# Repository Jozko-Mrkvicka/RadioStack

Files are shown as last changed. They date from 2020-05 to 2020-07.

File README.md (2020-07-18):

TODO
====
- Software AVR:
	- Change folder structure in some more sensible way.
	- Polish header files + including.
	- I can`t include delay.h to other files than main one. Find out why and replace all workarounds.
	- Add keyword const to all function declarations where possible.
	- Add description to all functions and describe all input and output parameters.
	- Add description to all modules.
	- There is potential problem with settings of bits in registers to zero. I do it incorrectly. Fix it!!

- Eagle:
	- ADF:
		- Change ELMA encoder to "normal" (single) one.
		- Display will be selected with push button on encoder.
		- Decimal point will define which display is currently selected.
		- Adjust DWG accordingly
		- Draw first board.
		- Think about second board (find out how many more IO modules can be added to the address space).

- Buy:
	- Jumpers.
	- Female pin headers with long pins.

- Other ideas:
	- ELMA encoders not fully working in one NavComm module. Probably mechanically damaged. Fix it or resolder.
	- Holes for buttons and knobs on NavComm module are too small. This problem should be already fixed in Eagle/AutoCAD drawings but check it once again.
	- Change front panel to plastic one:
		- It will be thicker. 
		- Add couple of bolts + nuts to attach it firmly to the rest of a module. 
		- It will have also bevelled edges. 
	- Encoder push buttons in NavComm modules not enabled yet. Add them.
	- Change pin headers to another ones with longer pins to create more space between PCB boards. The reason is to create more space for bolts/nuts to attach the device to a box/cover.

- Unsorted legacy mess:
	SVN
	===
	- nahrat vsetky dokumenty z mejlov (a mozno aj mejly samotne) do zlozky Admin
	- pridat vsetky subory eagle.epf na ignor list

	AutoCAD
	=======
	- zistit preco je XPDR tmavsi ako ostatne casti
	- vypatrat ci existuje nieco ako globalne konstanty/parametre, aby som mohol pouzivat rovnaky rozmer vo viacerych vykresoch
	- (XPDR) pridat objekt "obycajny" prepinac (ako bol na starom transponderu)

	Eagle
	=====
	- (niektore) Konektory na doske NavCom_Board_1 a NavCom_Board_2 su vlozene do vrstvy TOP, ale v skutocnosti sa nachadzaju vzadu (BOTTOM). To sposobi ze pri vyrobe sa ich obrysy vytlacia na opacnej strane dosky (tPlaces vs. bPlaces). Preto je treba tieto suciastky prehodit (Mirror) do spravnej vrstvy. 
	- NavComm 2.1/Board 2 - tlacitka T1 az T4 - trojice dierok pre piny su velmi blizko pri sebe, tlacitko nechce zaliezt do dierok (opravit aj v AutoCADe)
	- (nav/comm) mozno by bolo dobre odstranit vyvody na tlacitko "S" z enkoderov ELMA
	- ku kazdemu enkoderu pridat 2 kondenzatory
	- prepisat popisky tlacitiek T1 az T4 na BTN1 az BTN4

	Programovanie
	=============
	- vysvetlit naco sluzi signal Latch Reset
	- presunut radiostack.h zo zlozky modules/include do common/includes, alebo daco podobne

	Kupit
	=====
	- Dutinková lišta BL810GD
	- este jednu Elmu + hmatniky
	- jumpery
	- MCP23016 (2x)
	- 279-RGP0207CHJ470M (16x odpor z Mouseru)
	- dual shaft/dual concentric enkoder (2 channels) - Mouser
	- doniest z domu ockovy kluc kvoli hmatniku na Elmu
	- 2x Avago HDSP-711E

	======================================================================
	// -c		 skompiluje zdrojak ".c" do objektoveho kodu ".o"
	// -Wall	 warning all
	// -pedantic
	// -o 		 pomenuje vystupny subor
	avr-gcc -c pokus.c -Wall -pedantic -o vystup.o

	// zkompiluje a zlinkuje do ".exe"
	avr-gcc pokus.c libkniznica.a

	// -q	quick append - zalozi archiv / prida ".o" subor do archivu
	avr-ar -q libfnc.a fnc3.o

	// -t	zobrazi vsetky ".o" subory v archive
	avr-ar -t libfnc.a

	// -d	delete - vymaze ".o" subor z archivu
	avr-ar -d libfnc.a fnc3.o

	// -p 	typ procesoru (m8, t13, t2313, ...)
	// -c 	typ programatoru (AVRispmkII)
	// -P 	port ku ktoremu je programator pripojeny (usb)
	// -U 	<typ pamate>:<zapis/citanie>:<subor>:<format dat>
	//		<typ pamate>	flash, eeprom, hfuse, lfuse
	//		<zapis/citanie>	r, w
	//		<subor>			nazov suboru, napr. pokus.hex
	//		<format dat>	i (intel)		
	avrdude -p m8 -c avrispmkii -P usb -U flash:w:pokus.hex:i

	avr-gcc -mmcu=atmega8 -o demo.o -c demo.c 
	avr-gcc -mmcu=atmega8 -o demo.elf demo.o
	avr-objcopy -j .text -j .data -O ihex flash.elf flash.hex

	avrdude -p m8 -c AVRispmkII -P usb -U lfuse:w:0xff:m
	avrdude -p m8 -c AVRispmkII -P usb -U hfuse:w:0xd9:m
	avrdude -p m8 -c AVRispmkII -P usb -U flash:w:bin/radiostack.hex:i

	/////////////////////////////////////////////////////////////
	// Timer/Counter Interrupt Mask Register
	// TIMSK = 0x01;

	// iba pokus
	// Timer/Counter Control Register
	// TCCR0 = 0x01;

	// iba pokus
	// Timer/Counter Register - initial value
	// TCNT0 = 0x00;

	ISR (INT0_vect)
	{
		interruption = 1;

		// overflow++;

		// if (overflow < 300)
		// 	inc = 5;

		// else if ((overflow >= 300) && (overflow < 400))
		// 	inc = 4;

		// else if ((overflow >= 400) && (overflow < 500))
		// 	inc = 3;

		// else if ((overflow >= 500) && (overflow < 600))
		// 	inc = 2;

		// else if ((overflow >= 600) /*&& (overflow < 600)*/)
		//  inc = 1;

		// overflow = 0;
	}

	// ISR (TIMER0_OVF_vect)
	// {
	// 	if (overflow < 2000)
	// 		overflow++;
	// }
	/////////////////////////////////////////////////////////////

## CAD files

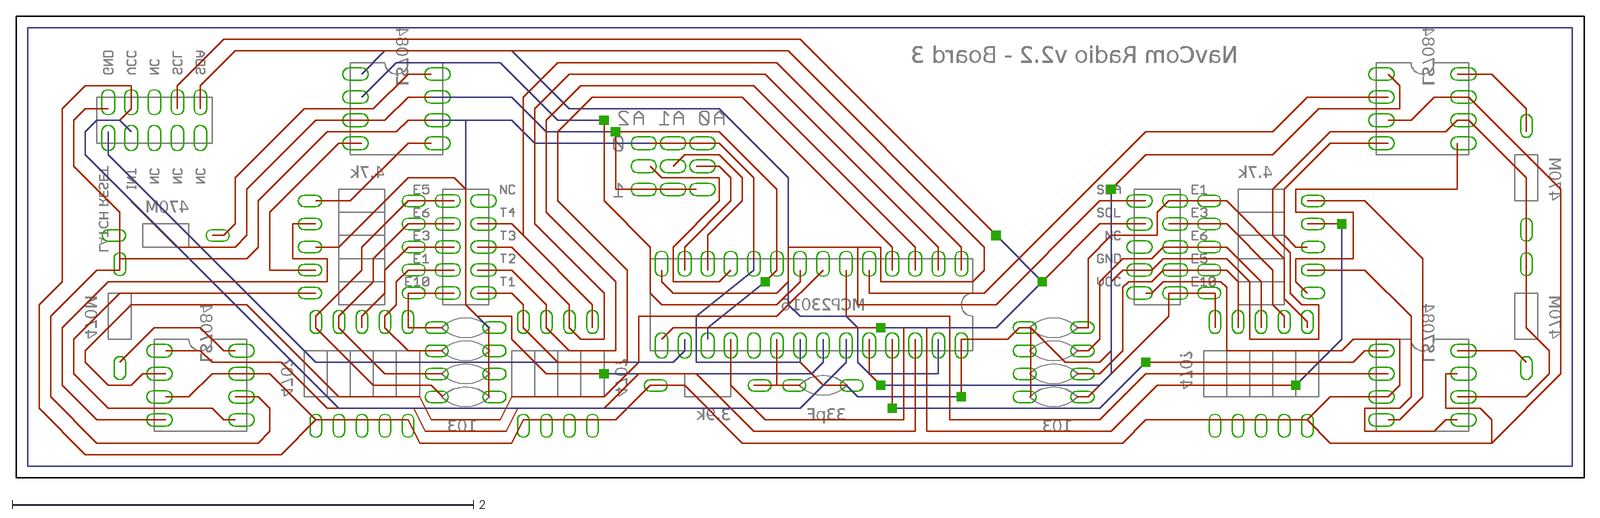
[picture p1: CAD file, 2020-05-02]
Schematics_Eagle/NavCom/NavCom_Board_3.dxf
NavCom Radio v2.2 - Board 3
LATCH RESET
33pF
MCP23016
LS7084
470?
3.9k
103
470M
4.7k

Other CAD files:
panel_only_c172__original.dwg
Schematics_AutoCAD/ADF/ADF.dwg
Schematics_AutoCAD/ADF/ADF_parts/ADF_panel.dwg
Schematics_AutoCAD/AP/AP.dwg
Schematics_AutoCAD/AP/AP_parts/AP_PCB.dwg
Schematics_AutoCAD/DME/DME.dwg
Schematics_AutoCAD/DME/DME_parts/DME_PCB.dwg
Schematics_AutoCAD/NavCom/NavCom.dwg
Schematics_AutoCAD/NavCom/NavCom_parts/NavCom_panel.dwg
Schematics_AutoCAD/RadioStack.dwg
Schematics_AutoCAD/XPDR/XPDR.dwg
Schematics_AutoCAD/XPDR/XPDR_parts/XPDR_PCB.dwg
Schematics_Inventor/Výkres1.dwg
Schematics_AutoCAD/ADF/ADF_parts/ADF_PCB.dwg
Schematics_AutoCAD/AP/AP_parts/AP_plexi.dwg
Schematics_AutoCAD/DME/DME_parts/DME_plexi.dwg
Schematics_AutoCAD/NavCom/NavCom_parts/NavCom_PCB.dwg
Schematics_AutoCAD/ADF/ADF_parts/ADF_mask.dwg
Schematics_AutoCAD/ADF/ADF_parts/ADF_plexi.dwg
Schematics_AutoCAD/AP/AP_parts/AP_mask.dwg
Schematics_AutoCAD/AP/AP_parts/AP_panel.dwg
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

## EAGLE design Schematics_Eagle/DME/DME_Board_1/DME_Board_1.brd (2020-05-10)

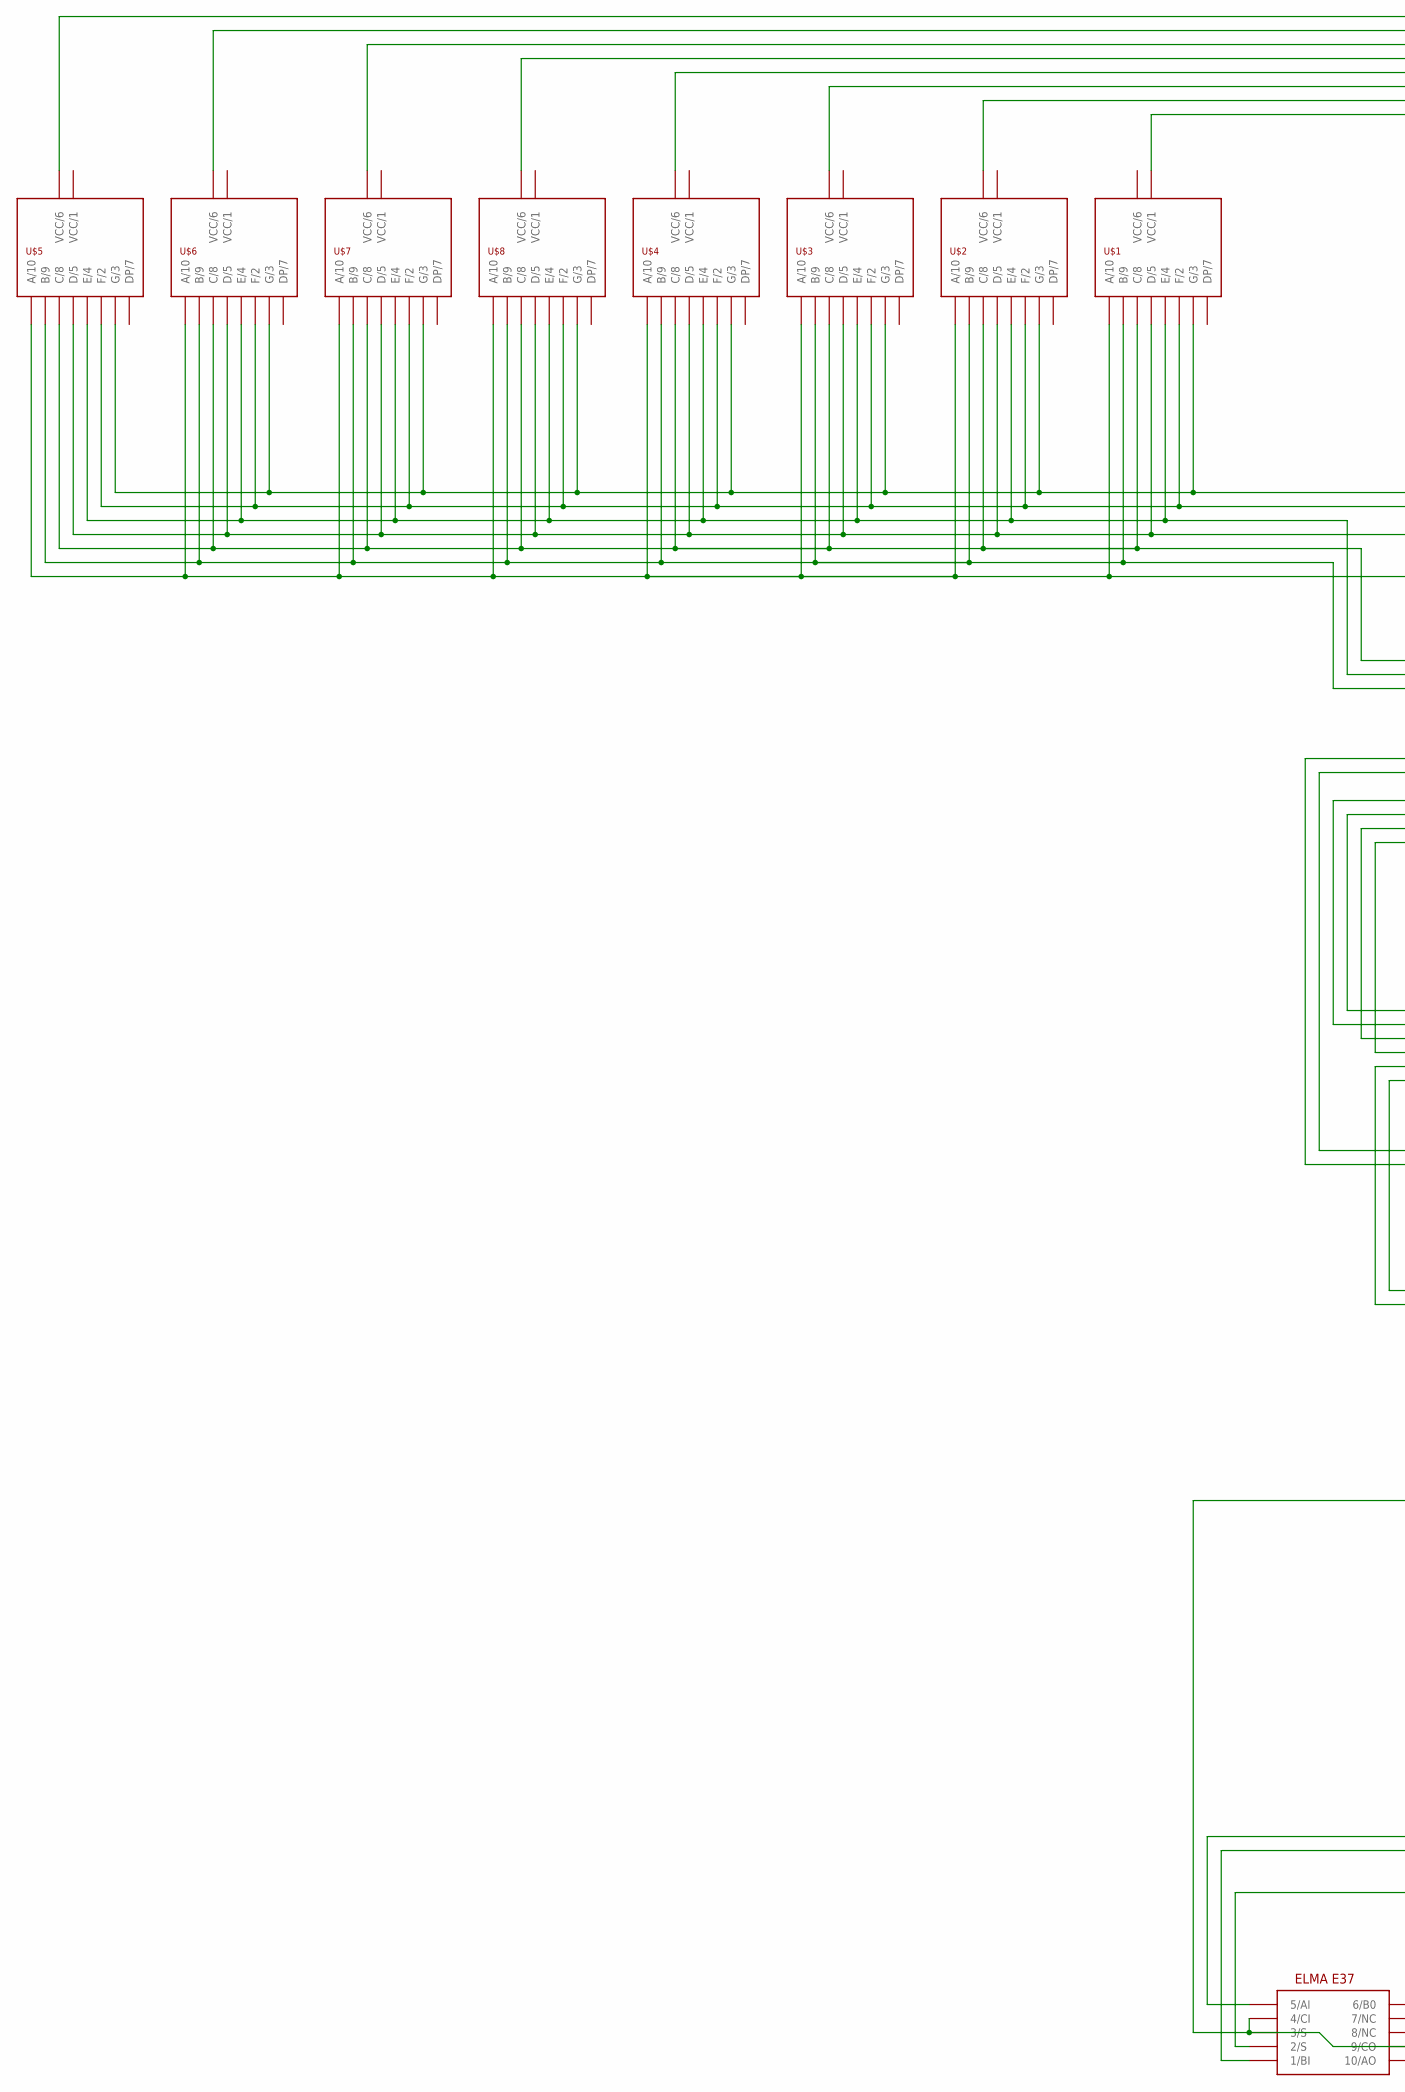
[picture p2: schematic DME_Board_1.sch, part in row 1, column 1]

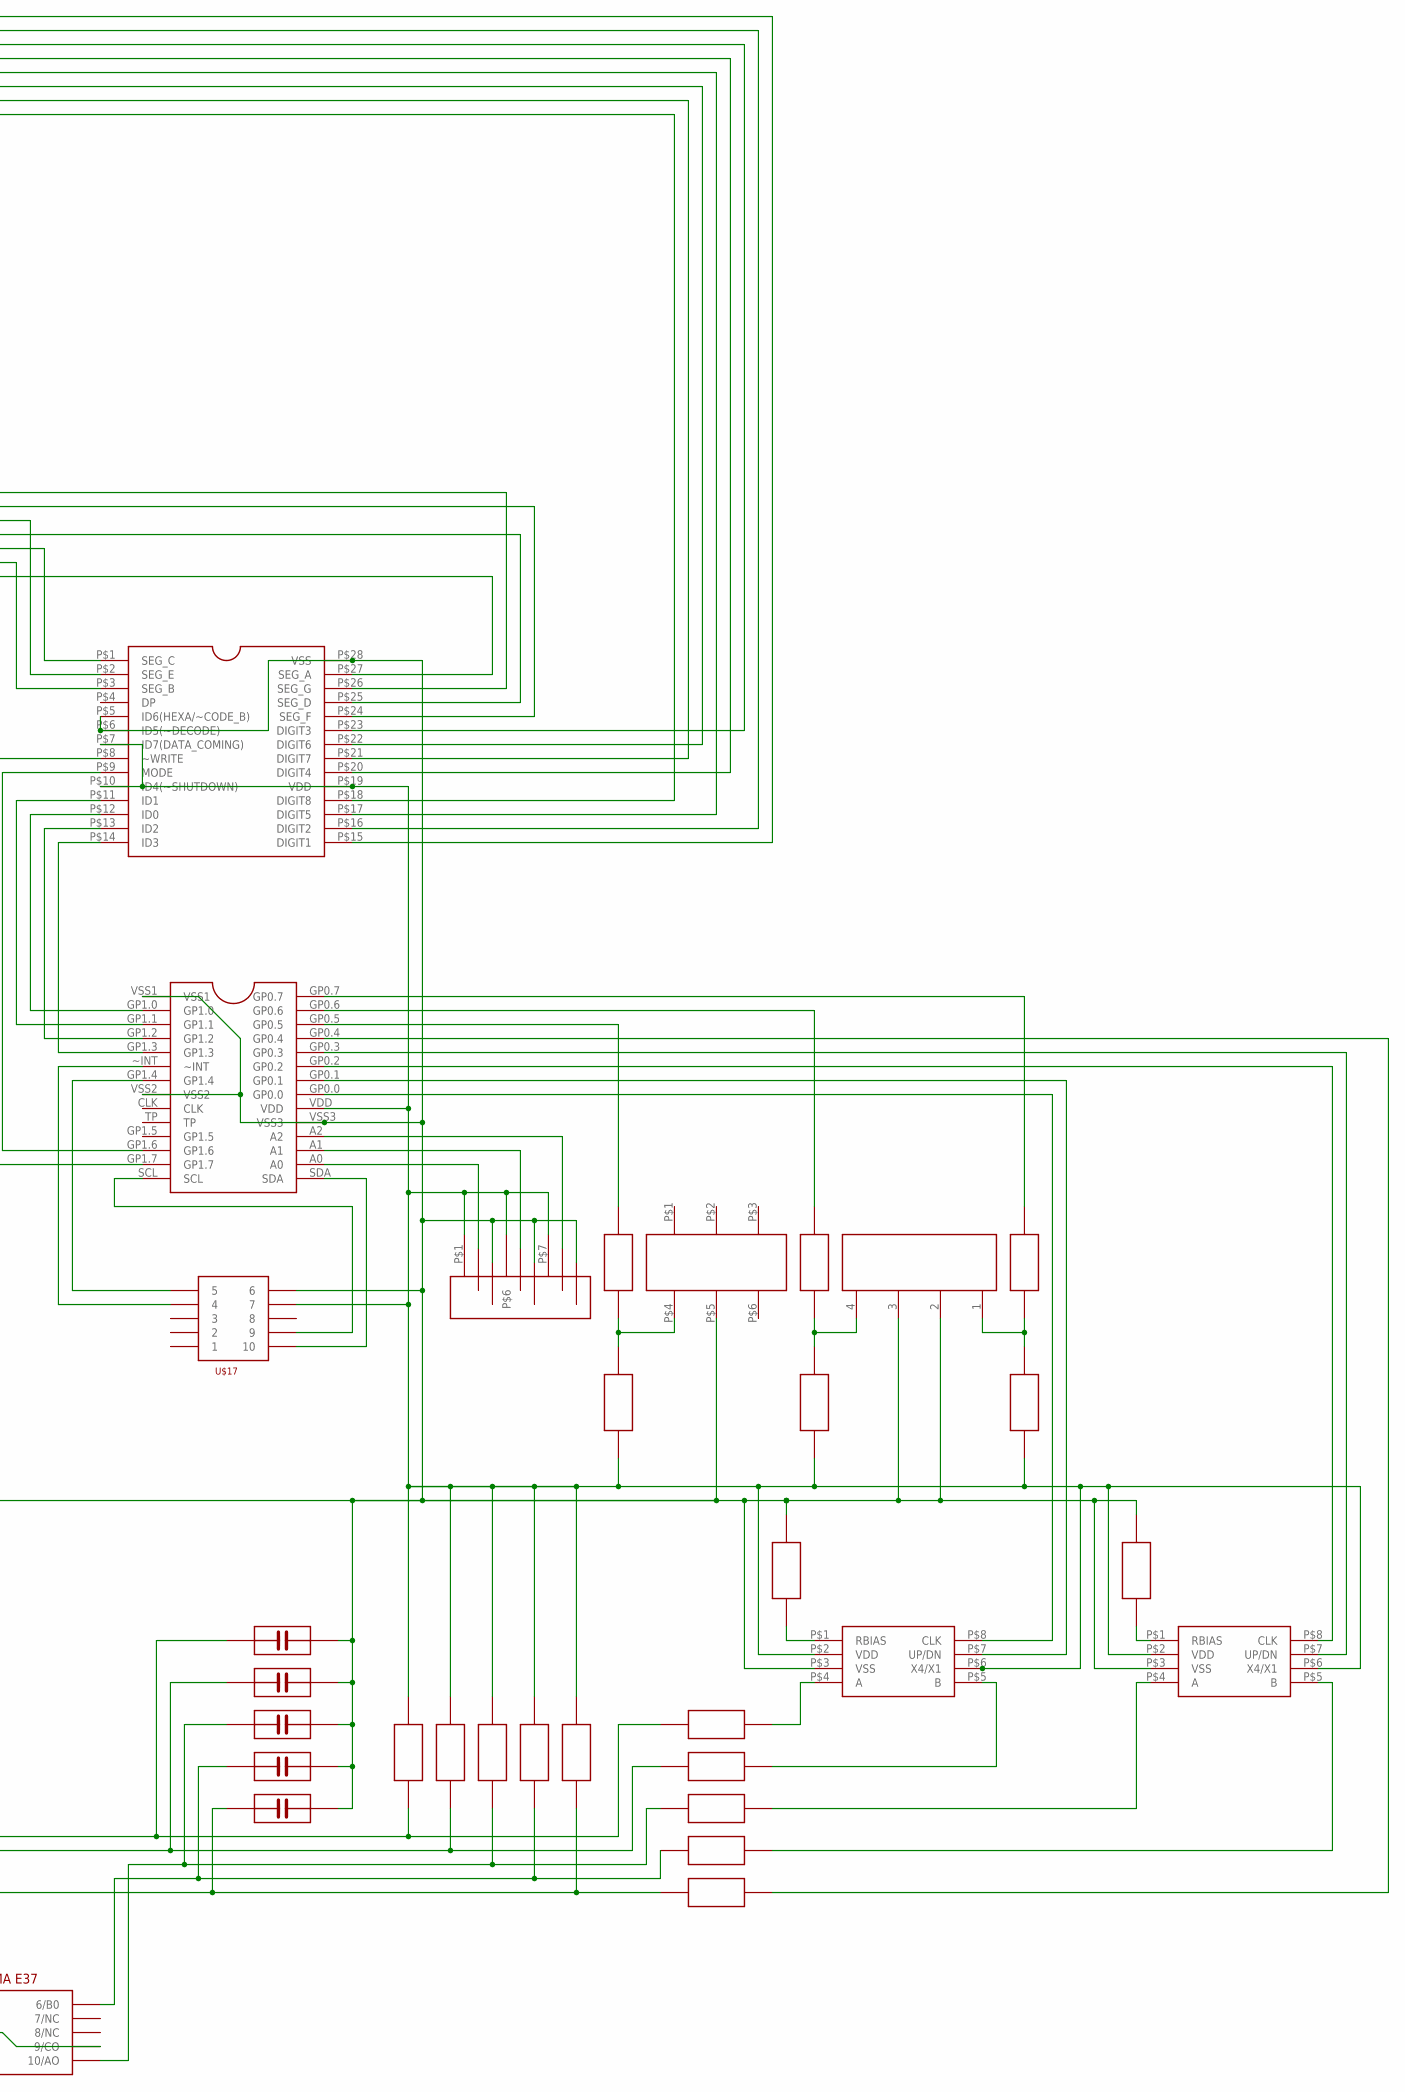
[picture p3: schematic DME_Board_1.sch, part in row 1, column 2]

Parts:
U$1, U$2, U$3, U$4, U$5, U$6, U$7, U$8: SA3611EWA
U$9: ELMA_E37
U$10, U$13, U$15, U$20, U$21, U$22, U$23, U$25, U$26, U$27, U$28, U$29, U$30, U$31, U$32, U$33, U$34, U$35: REZISTOR
U$11, U$42, U$43, U$44: KONDENZATOR
U$12: T220
U$14: ICM7228A
U$16: MCP23016
U$17: LISTA_2X5
U$18, U$46: LS7084
U$19: 46311LD
U$24: ADRESA_0..2
U$45: 103; KONDENZATOR

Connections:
unnamed: U$1.10 (A/10), U$2.10 (A/10), U$3.10 (A/10), U$4.10 (A/10), U$5.10 (A/10), U$6.10 (A/10), U$7.10 (A/10), U$8.10 (A/10), U$14.P$27 (SEG_A)
unnamed: U$1.9 (B/9), U$2.9 (B/9), U$3.9 (B/9), U$4.9 (B/9), U$5.9 (B/9), U$6.9 (B/9), U$7.9 (B/9), U$8.9 (B/9), U$14.P$3 (SEG_B)
unnamed: U$1.8 (C/8), U$2.8 (C/8), U$3.8 (C/8), U$4.8 (C/8), U$5.8 (C/8), U$6.8 (C/8), U$7.8 (C/8), U$8.8 (C/8), U$14.P$1 (SEG_C)
unnamed: U$1.5 (D/5), U$2.5 (D/5), U$3.5 (D/5), U$4.5 (D/5), U$5.5 (D/5), U$6.5 (D/5), U$7.5 (D/5), U$8.5 (D/5), U$14.P$25 (SEG_D)
unnamed: U$5.6 (VCC/6), U$14.P$15 (DIGIT1)
unnamed: U$1.2 (F/2), U$2.2 (F/2), U$3.2 (F/2), U$4.2 (F/2), U$5.2 (F/2), U$6.2 (F/2), U$7.2 (F/2), U$8.2 (F/2), U$14.P$24 (SEG_F)
unnamed: U$1.3 (G/3), U$2.3 (G/3), U$3.3 (G/3), U$4.3 (G/3), U$5.3 (G/3), U$6.3 (G/3), U$7.3 (G/3), U$8.3 (G/3), U$14.P$26 (SEG_G)
unnamed: U$6.6 (VCC/6), U$14.P$16 (DIGIT2)
unnamed: U$1.4 (E/4), U$2.4 (E/4), U$3.4 (E/4), U$4.4 (E/4), U$5.4 (E/4), U$6.4 (E/4), U$7.4 (E/4), U$8.4 (E/4), U$14.P$2 (SEG_E)
unnamed: U$7.6 (VCC/6), U$14.P$23 (DIGIT3)
unnamed: U$8.6 (VCC/6), U$14.P$20 (DIGIT4)
unnamed: U$1.1 (VCC/1), U$14.P$18 (DIGIT8)
unnamed: U$2.6 (VCC/6), U$14.P$21 (DIGIT7)
unnamed: U$3.6 (VCC/6), U$14.P$22 (DIGIT6)
unnamed: U$4.6 (VCC/6), U$14.P$17 (DIGIT5)
unnamed: U$16.GP0.5, U$23.P$2
unnamed: U$9.1 (1/BI), U$11.P$1, U$25.P$1, U$32.P$2
unnamed: U$14.P$12 (ID0), U$16.GP1.0
unnamed: U$14.P$11 (ID1), U$16.GP1.1
unnamed: U$14.P$13 (ID2), U$16.GP1.2
unnamed: U$14.P$14 (ID3), U$16.GP1.3
unnamed: U$14.P$9 (MODE), U$16.GP1.6
unnamed: U$14.P$8 (~WRITE), U$16.GP1.7
unnamed: U$16.A0, U$24.P$2
unnamed: U$10.P$1, U$13.P$1, U$14.P$7 (ID7(DATA_COMING)), U$14.P$10 (ID4(~SHUTDOWN)), U$14.P$19 (VDD), U$15.P$1, U$16.VDD, U$17.7, U$18.P$2 (VDD), U$18.P$6 (X4/X1), U$20.P$2, U$24.P$1, U$24.P$6, U$24.P$7, U$25.P$2, U$26.P$2, U$27.P$2, U$28.P$2, U$46.P$2 (VDD), U$46.P$6 (X4/X1)
unnamed: U$31.P$1, U$46.P$4 (A)
unnamed: U$30.P$1, U$46.P$5 (B)
unnamed: U$9.10 (10/AO), U$26.P$1, U$31.P$2, U$43.P$1
unnamed: U$9.2 (2/S), U$28.P$1, U$29.P$2, U$45.P$1
unnamed: U$9.6 (6/B0), U$27.P$1, U$30.P$2, U$44.P$1
unnamed: U$16.GP0.4, U$29.P$1
unnamed: U$18.P$4 (A), U$33.P$1
unnamed: U$16.A1, U$24.P$5
unnamed: U$35.P$1, U$46.P$1 (RBIAS)
unnamed: U$18.P$5 (B), U$32.P$1
unnamed: U$18.P$1 (RBIAS), U$34.P$1
unnamed: U$16.GP0.1, U$18.P$7 (UP/DN)
unnamed: U$16.GP0.0, U$18.P$8 (CLK)
unnamed: U$16.GP0.3, U$46.P$7 (UP/DN)
unnamed: U$16.GP0.2, U$46.P$8 (CLK)
unnamed: U$9.5 (5/AI), U$20.P$1, U$33.P$2, U$42.P$1
unnamed: U$16.A2, U$24.P$8
unnamed: U$10.P$2, U$12.P$4, U$23.P$1
unnamed: U$9.3 (3/S), U$9.4 (4/CI), U$9.9 (9/CO), U$11.P$2, U$12.P$5, U$14.P$5 (ID6(HEXA/~CODE_B)), U$14.P$6 (ID5(~DECODE)), U$14.P$28 (VSS), U$16.VSS1, U$16.VSS2, U$16.VSS3, U$17.6, U$18.P$3 (VSS), U$19.2, U$19.3, U$24.P$3, U$24.P$4, U$24.P$9, U$34.P$2, U$35.P$2, U$42.P$2, U$43.P$2, U$44.P$2, U$45.P$2, U$46.P$3 (VSS)
unnamed: U$13.P$2, U$19.4, U$22.P$1
unnamed: U$15.P$2, U$19.1, U$21.P$1
unnamed: U$16.GP0.6, U$22.P$2
unnamed: U$16.GP0.7, U$21.P$2
unnamed: U$16.SDA, U$17.10
unnamed: U$16.SCL, U$17.9
unnamed: U$16.GP1.4, U$17.5
unnamed: U$16.~INT, U$17.4

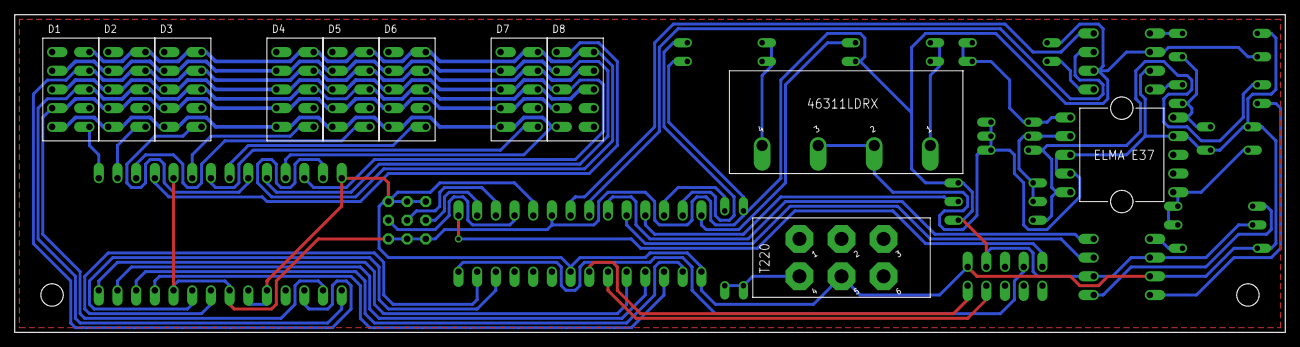
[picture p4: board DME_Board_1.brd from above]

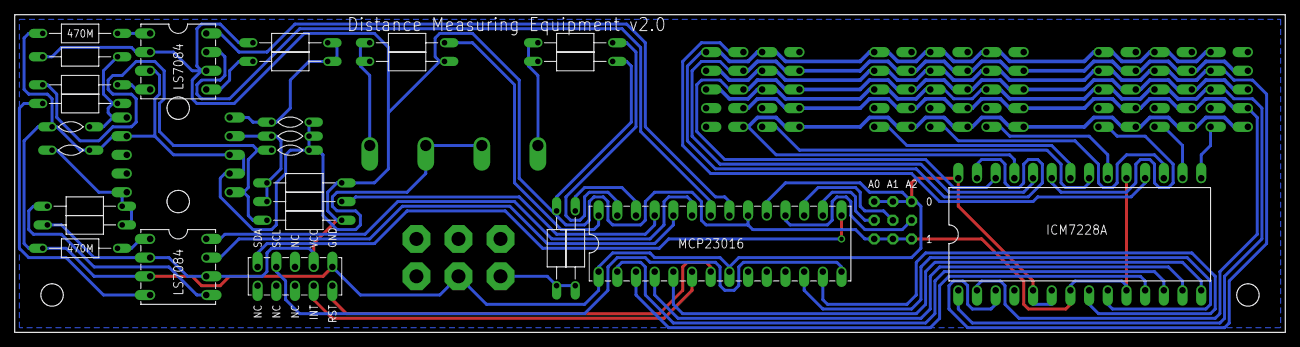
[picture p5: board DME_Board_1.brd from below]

Board: 2 copper layers, 172.7 x 43.2 mm, 40 parts (28 on the bottom side), 52 nets.

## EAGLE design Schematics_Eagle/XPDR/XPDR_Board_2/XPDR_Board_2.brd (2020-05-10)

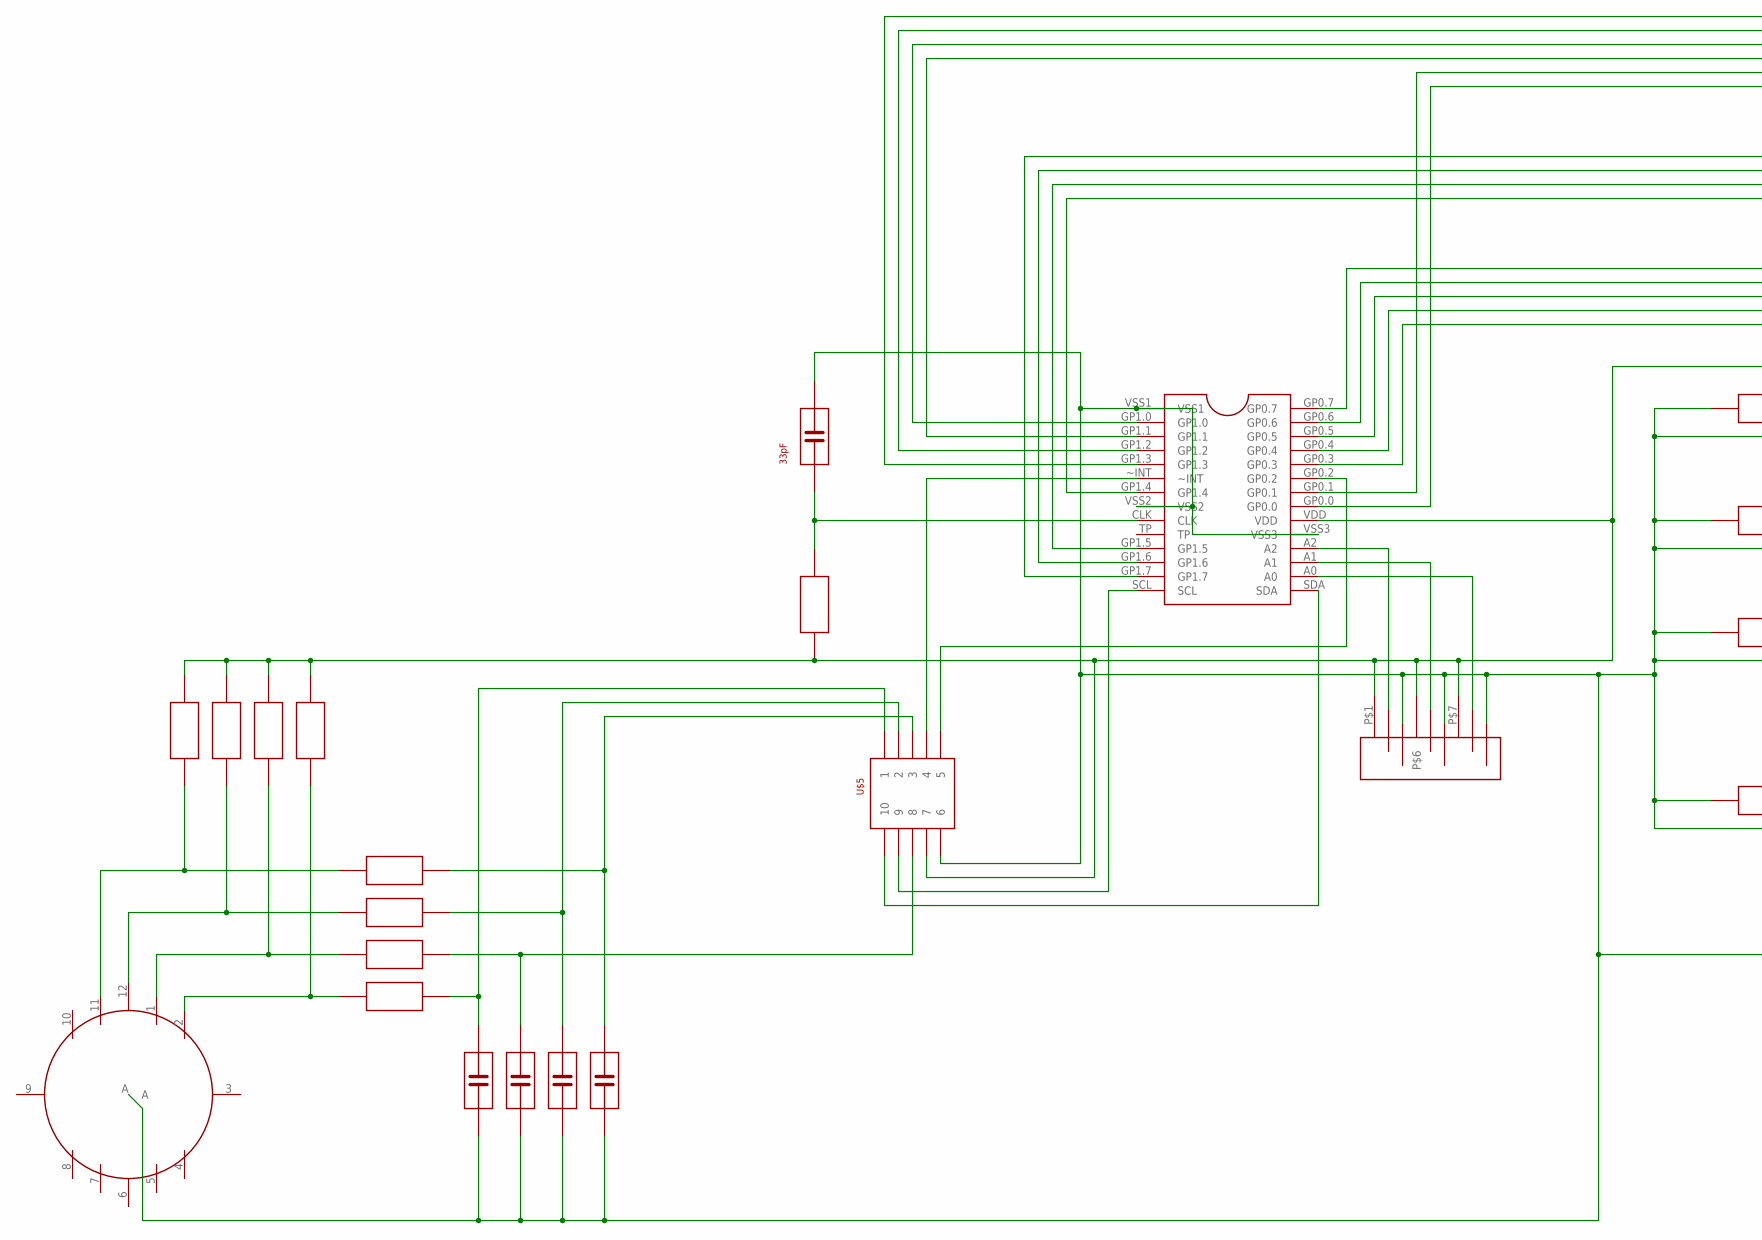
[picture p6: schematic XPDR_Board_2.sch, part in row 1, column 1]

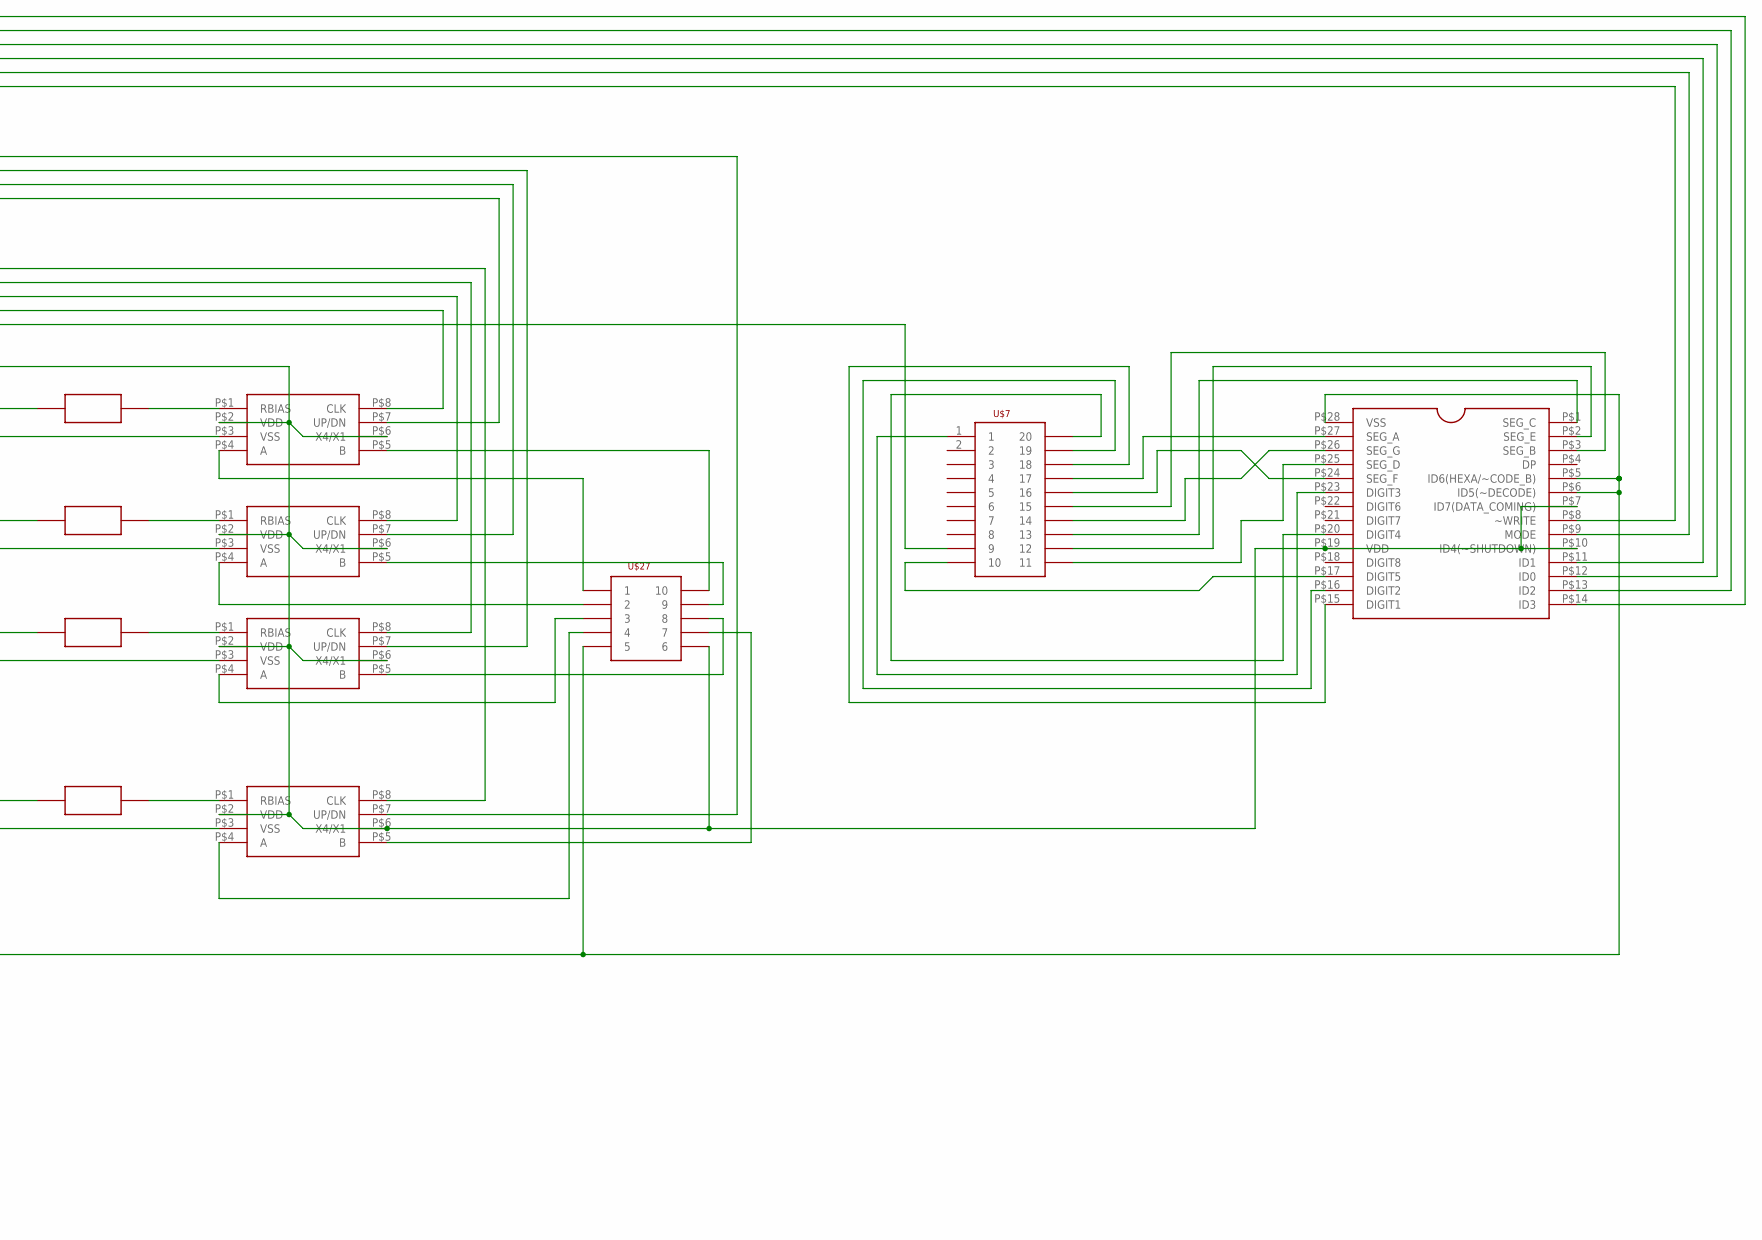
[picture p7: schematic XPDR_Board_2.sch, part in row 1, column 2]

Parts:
U$1, U$2, U$3, U$4: LS7084
U$5, U$27: LISTA_2X5
U$6: ICM7228A
U$7: LISTA_2X10
U$8, U$10, U$12, U$13: 470M; REZISTOR
U$9: MCP23016
U$11: ADRESA_0..2
U$14: 3.9k; REZISTOR
U$15: 33pF; KONDENZATOR
U$16: ROTARY_SWITCH
U$17, U$18, U$19, U$20, U$21, U$22, U$23, U$24: REZISTOR
U$25, U$26, U$28, U$29: KONDENZATOR

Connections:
GND: U$1.P$3 (VSS), U$2.P$3 (VSS), U$3.P$3 (VSS), U$4.P$3 (VSS), U$5.6, U$6.P$5 (ID6(HEXA/~CODE_B)), U$6.P$6 (ID5(~DECODE)), U$6.P$28 (VSS), U$8.P$1, U$9.VSS1, U$9.VSS2, U$9.VSS3, U$10.P$1, U$11.P$3, U$11.P$4, U$11.P$9, U$12.P$1, U$13.P$1, U$15.P$2, U$16.A, U$25.P$1, U$26.P$1, U$27.5, U$28.P$1, U$29.P$1
unnamed: U$6.P$27 (SEG_A), U$7.17
unnamed: U$6.P$24 (SEG_F), U$7.16
unnamed: U$6.P$3 (SEG_B), U$7.15
unnamed: U$6.P$26 (SEG_G), U$7.14
unnamed: U$6.P$1 (SEG_C), U$7.13
unnamed: U$6.P$2 (SEG_E), U$7.12
unnamed: U$6.P$25 (SEG_D), U$7.11
unnamed: U$6.P$15 (DIGIT1), U$7.18
unnamed: U$6.P$16 (DIGIT2), U$7.19
unnamed: U$6.P$23 (DIGIT3), U$7.1
unnamed: U$6.P$20 (DIGIT4), U$7.20
unnamed: U$1.P$2 (VDD), U$1.P$6 (X4/X1), U$2.P$2 (VDD), U$2.P$6 (X4/X1), U$3.P$2 (VDD), U$3.P$6 (X4/X1), U$4.P$2 (VDD), U$4.P$6 (X4/X1), U$5.7, U$6.P$7 (ID7(DATA_COMING)), U$6.P$10 (ID4(~SHUTDOWN)), U$6.P$19 (VDD), U$9.VDD, U$11.P$1, U$11.P$6, U$11.P$7, U$14.P$1, U$17.P$1, U$18.P$1, U$19.P$1, U$20.P$1, U$27.6
unnamed: U$6.P$12 (ID0), U$9.GP1.0
unnamed: U$1.P$8 (CLK), U$9.GP0.4
unnamed: U$2.P$8 (CLK), U$9.GP0.5
unnamed: U$1.P$1 (RBIAS), U$8.P$2
unnamed: U$2.P$1 (RBIAS), U$10.P$2
unnamed: U$3.P$1 (RBIAS), U$12.P$2
unnamed: U$4.P$1 (RBIAS), U$13.P$2
unnamed: U$6.P$11 (ID1), U$9.GP1.1
unnamed: U$3.P$8 (CLK), U$9.GP0.6
unnamed: U$4.P$8 (CLK), U$9.GP0.7
unnamed: U$1.P$7 (UP/DN), U$9.GP1.4
unnamed: U$1.P$4 (A), U$27.1
unnamed: U$1.P$5 (B), U$27.10
unnamed: U$2.P$4 (A), U$27.2
unnamed: U$2.P$5 (B), U$27.9
unnamed: U$3.P$4 (A), U$27.3
unnamed: U$3.P$5 (B), U$27.8
unnamed: U$4.P$4 (A), U$27.4
unnamed: U$4.P$5 (B), U$27.7
unnamed: U$2.P$7 (UP/DN), U$9.GP1.5
unnamed: U$3.P$7 (UP/DN), U$9.GP1.6
unnamed: U$4.P$7 (UP/DN), U$9.GP1.7
unnamed: U$9.A0, U$11.P$8
unnamed: U$9.A1, U$11.P$5
unnamed: U$9.A2, U$11.P$2
unnamed: U$6.P$13 (ID2), U$9.GP1.2
unnamed: U$6.P$14 (ID3), U$9.GP1.3
unnamed: U$16.11, U$17.P$2, U$21.P$2
unnamed: U$6.P$8 (~WRITE), U$9.GP0.0
unnamed: U$6.P$9 (MODE), U$9.GP0.1
unnamed: U$16.12, U$18.P$2, U$22.P$2
unnamed: U$5.9, U$9.SCL
unnamed: U$5.10, U$9.SDA
unnamed: U$5.4, U$9.~INT
unnamed: U$5.5, U$9.GP0.2
unnamed: U$9.CLK, U$14.P$2, U$15.P$1
unnamed: U$7.9, U$9.GP0.3
unnamed: U$6.P$17 (DIGIT5), U$7.10
unnamed: U$16.1, U$19.P$2, U$23.P$2
unnamed: U$16.2, U$20.P$2, U$24.P$2
unnamed: U$5.8, U$23.P$1, U$26.P$2
unnamed: U$5.2, U$22.P$1, U$28.P$2
unnamed: U$5.3, U$21.P$1, U$29.P$2
unnamed: U$5.1, U$24.P$1, U$25.P$2

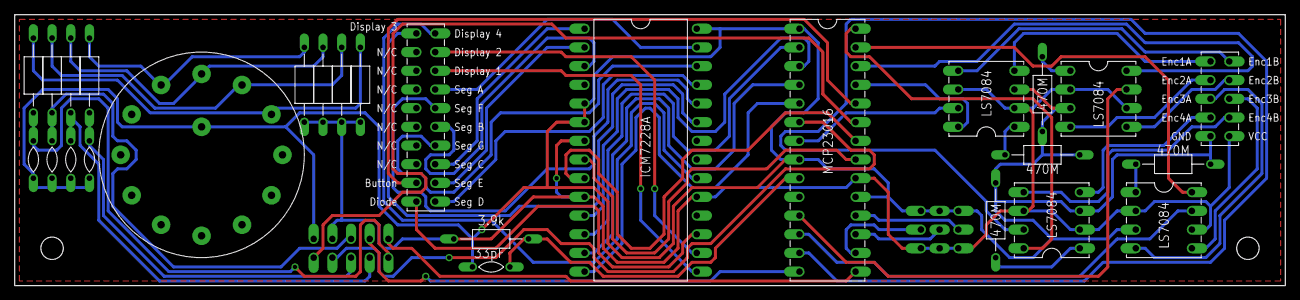
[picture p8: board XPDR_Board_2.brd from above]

Board: 2 copper layers, 172.7 x 36.8 mm, 29 parts (1 on the bottom side), 57 nets.

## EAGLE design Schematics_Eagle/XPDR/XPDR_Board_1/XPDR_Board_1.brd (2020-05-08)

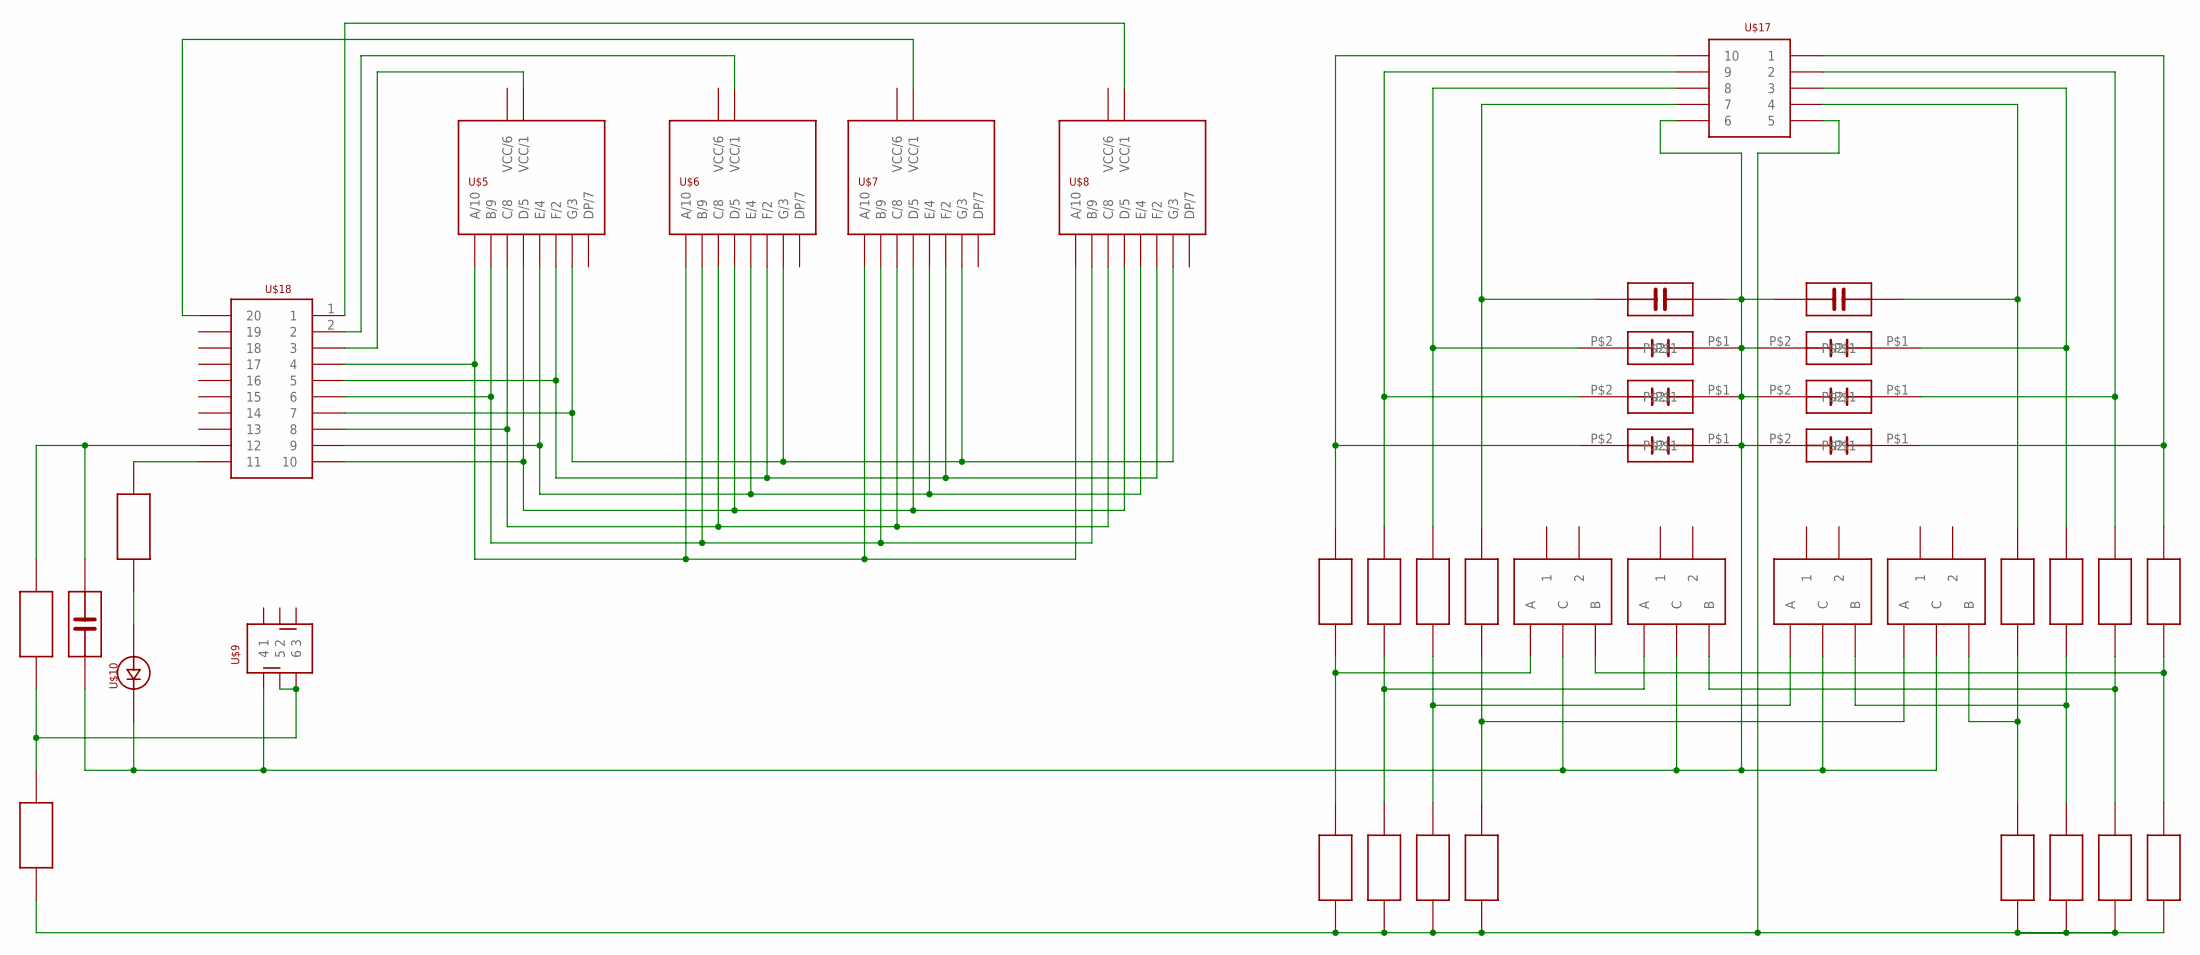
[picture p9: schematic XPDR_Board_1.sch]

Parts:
U$1, U$2, U$3, U$4: PEC11R
U$5, U$6, U$7, U$8: SA3611EWA
U$9: P1-0S
U$10: LED_5MM
U$11, U$12, U$13, U$14, U$15, U$16, U$19, U$20, U$21, U$22, U$23, U$24, U$25, U$26, U$27, U$28, U$30, U$31, U$40: REZISTOR
U$17: LISTA_2X5
U$18: LISTA_2X10
U$29, U$32, U$33, U$35, U$36, U$37: KONDENZATOR_SIROKY
U$34, U$38, U$39: KONDENZATOR

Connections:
unnamed: U$5.10 (A/10), U$6.10 (A/10), U$7.10 (A/10), U$8.10 (A/10), U$18.4
unnamed: U$5.9 (B/9), U$6.9 (B/9), U$7.9 (B/9), U$8.9 (B/9), U$18.6
unnamed: U$5.8 (C/8), U$6.8 (C/8), U$7.8 (C/8), U$8.8 (C/8), U$18.8
unnamed: U$5.5 (D/5), U$6.5 (D/5), U$7.5 (D/5), U$8.5 (D/5), U$18.10
unnamed: U$11.P$2, U$17.10, U$29.P$2
unnamed: U$5.2 (F/2), U$6.2 (F/2), U$7.2 (F/2), U$8.2 (F/2), U$18.5
unnamed: U$5.3 (G/3), U$6.3 (G/3), U$7.3 (G/3), U$8.3 (G/3), U$18.7
unnamed: U$1.B, U$12.P$1, U$27.P$1
unnamed: U$5.4 (E/4), U$6.4 (E/4), U$7.4 (E/4), U$8.4 (E/4), U$18.9
unnamed: U$13.P$2, U$17.9, U$32.P$2
unnamed: U$2.B, U$14.P$1, U$25.P$1
unnamed: U$15.P$2, U$17.8, U$33.P$2
unnamed: U$3.B, U$16.P$1, U$23.P$1
unnamed: U$17.7, U$19.P$2, U$34.P$2
unnamed: U$4.B, U$20.P$1, U$21.P$1
unnamed: U$5.1 (VCC/1), U$18.3
unnamed: U$6.1 (VCC/1), U$18.2
unnamed: U$7.1 (VCC/1), U$18.20
unnamed: U$8.1 (VCC/1), U$18.1
unnamed: U$9.5, U$9.6, U$30.P$2, U$31.P$1
unnamed: U$1.C, U$2.C, U$3.C, U$4.C, U$9.4, U$10.P$2, U$17.6, U$29.P$1, U$32.P$1, U$33.P$1, U$34.P$1, U$35.P$2, U$36.P$2, U$37.P$2, U$38.P$2, U$39.P$2
unnamed: U$1.A, U$11.P$1, U$28.P$1
unnamed: U$12.P$2, U$17.1, U$35.P$1
unnamed: U$17.5, U$21.P$2, U$22.P$2, U$23.P$2, U$24.P$2, U$25.P$2, U$26.P$2, U$27.P$2, U$28.P$2, U$31.P$2
unnamed: U$3.A, U$15.P$1, U$24.P$1
unnamed: U$18.11, U$40.P$1
unnamed: U$4.A, U$19.P$1, U$22.P$1
unnamed: U$14.P$2, U$17.2, U$36.P$1
unnamed: U$16.P$2, U$17.3, U$37.P$1
unnamed: U$17.4, U$20.P$2, U$38.P$1
unnamed: U$2.A, U$13.P$1, U$26.P$1
unnamed: U$10.P$1, U$40.P$2
unnamed: U$18.12, U$30.P$1, U$39.P$1

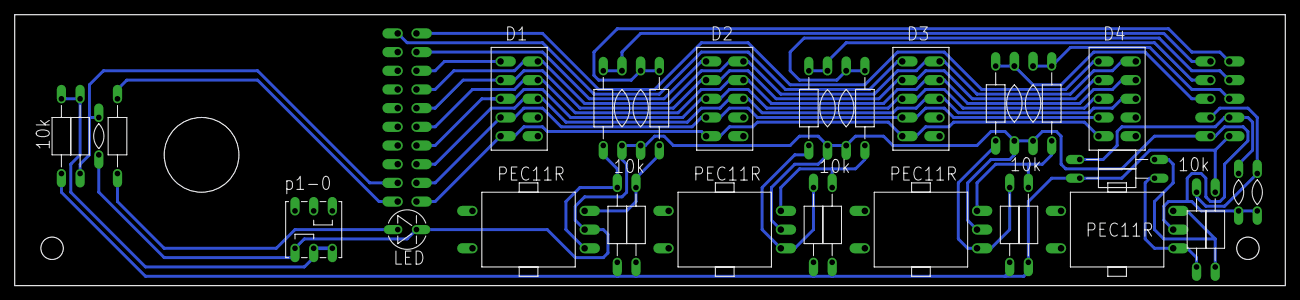
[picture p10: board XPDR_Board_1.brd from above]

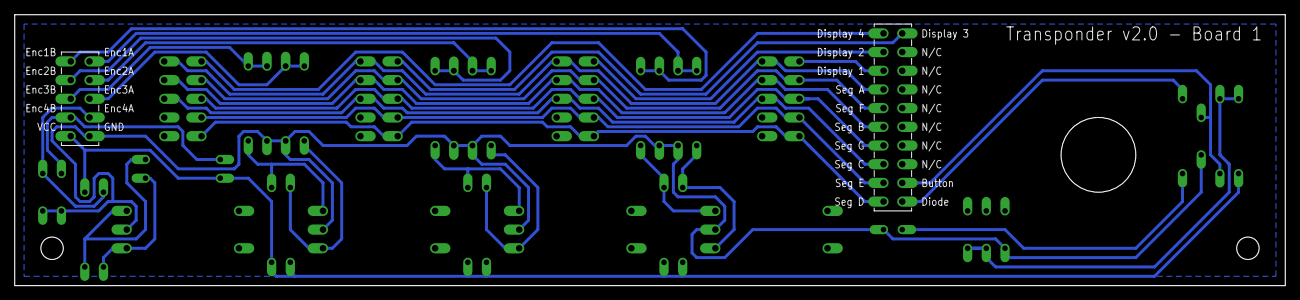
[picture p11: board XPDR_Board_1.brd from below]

Board: 2 copper layers, 172.7 x 36.8 mm, 40 parts (2 on the bottom side), 33 nets.

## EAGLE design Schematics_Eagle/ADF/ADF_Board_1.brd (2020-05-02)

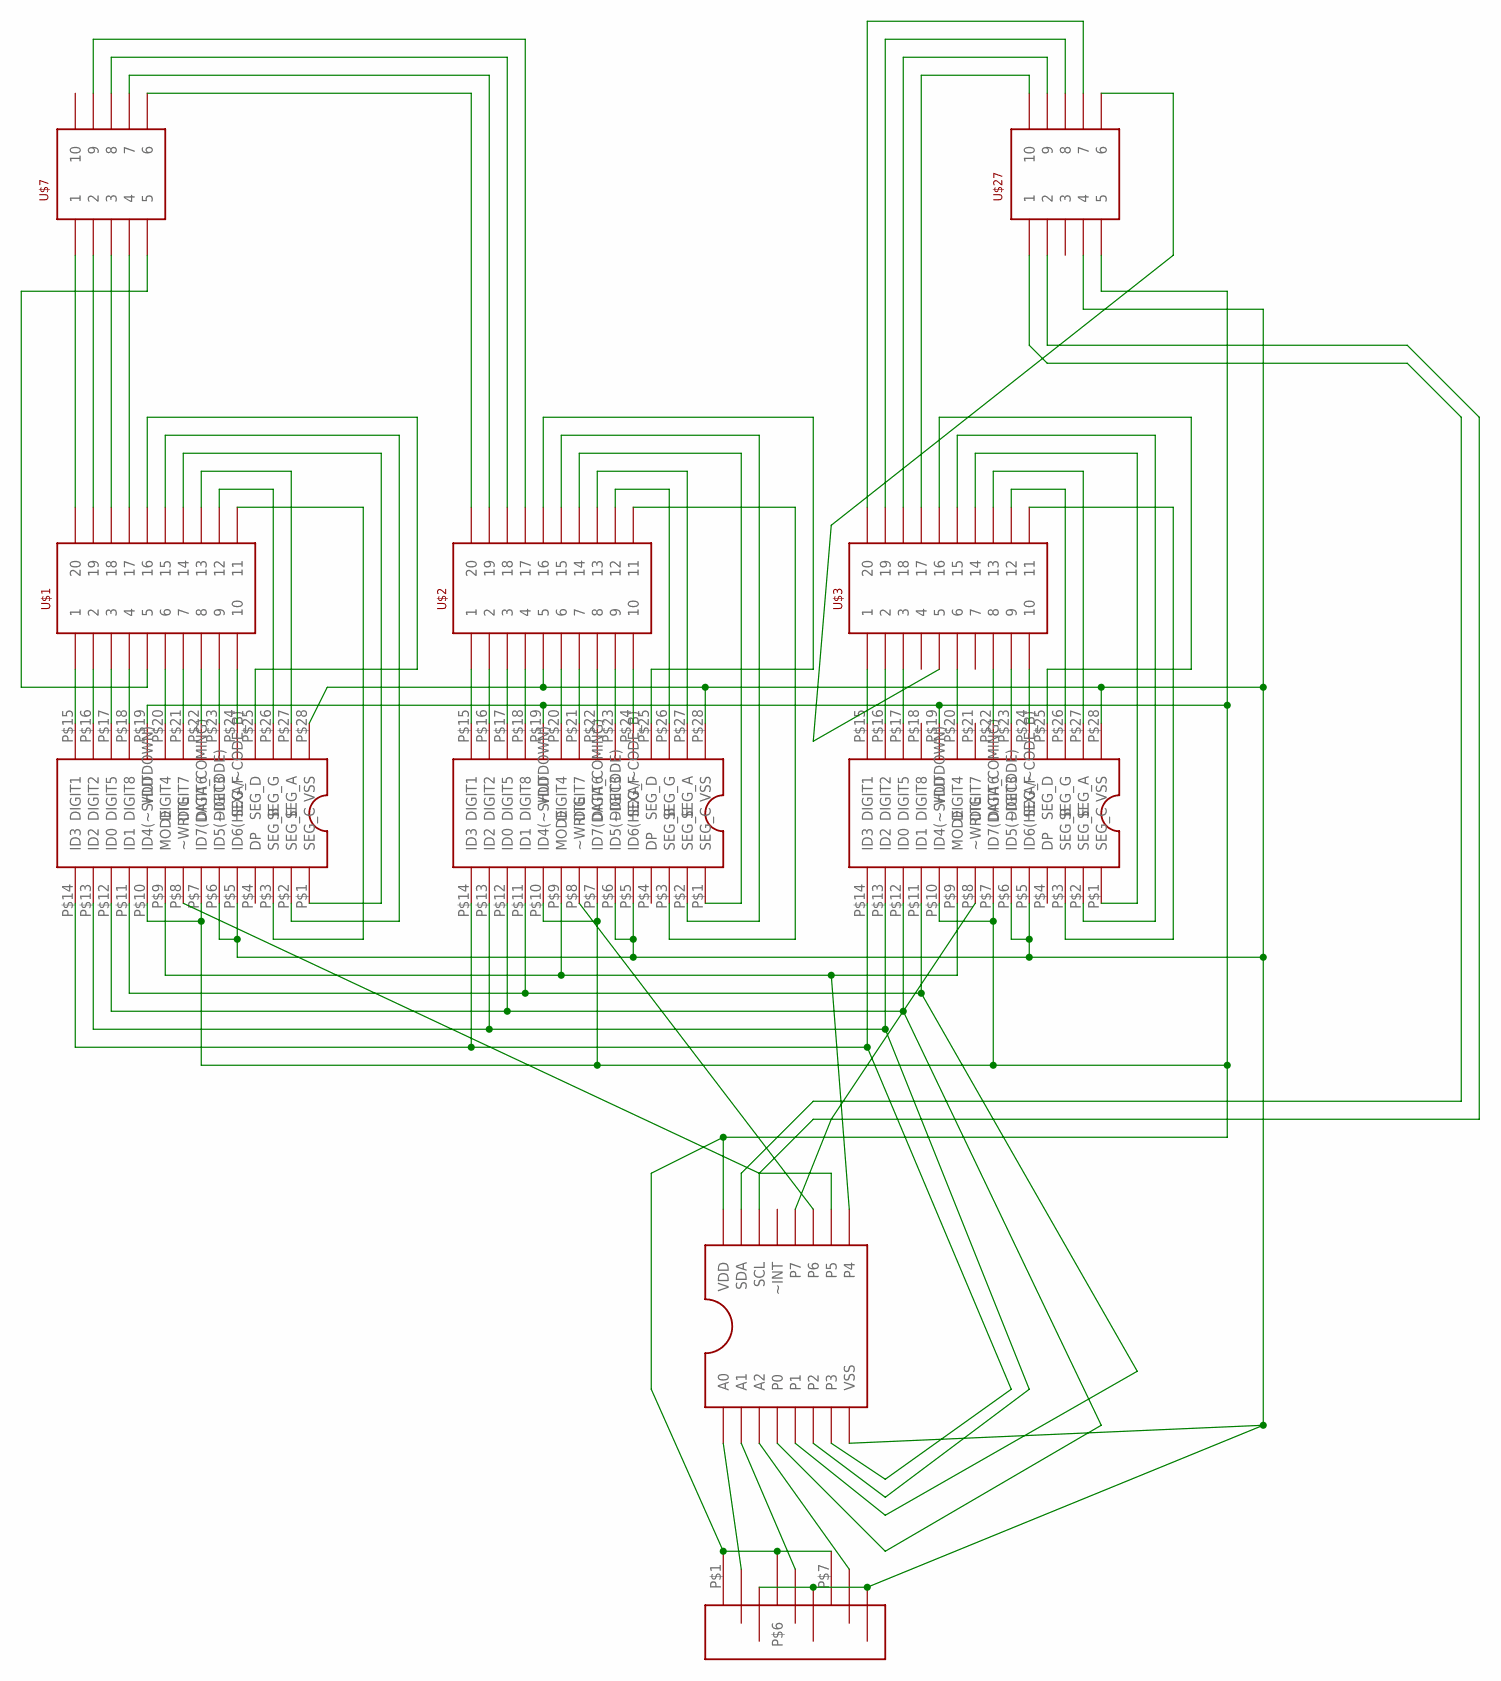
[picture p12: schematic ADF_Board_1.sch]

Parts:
U$1, U$2, U$3: LISTA_2X10
U$4, U$5, U$6: ICM7228A
U$7, U$27: LISTA_2X5
U$9: PCF8574A
U$11: ADRESA_0..2

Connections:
GND: U$2.5, U$4.P$5 (ID6(HEXA/~CODE_B)), U$4.P$6 (ID5(~DECODE)), U$4.P$28 (VSS), U$5.P$5 (ID6(HEXA/~CODE_B)), U$5.P$6 (ID5(~DECODE)), U$5.P$28 (VSS), U$6.P$5 (ID6(HEXA/~CODE_B)), U$6.P$6 (ID5(~DECODE)), U$6.P$28 (VSS), U$9.VSS, U$11.P$3, U$11.P$4, U$11.P$9, U$27.4
unnamed: U$1.1, U$4.P$15 (DIGIT1)
unnamed: U$2.1, U$5.P$15 (DIGIT1)
unnamed: U$1.2, U$4.P$16 (DIGIT2)
unnamed: U$1.3, U$4.P$17 (DIGIT5)
unnamed: U$1.4, U$4.P$18 (DIGIT8)
unnamed: U$1.11, U$4.P$3 (SEG_B)
unnamed: U$1.6, U$4.P$20 (DIGIT4)
unnamed: U$1.7, U$4.P$21 (DIGIT7)
unnamed: U$1.8, U$4.P$22 (DIGIT6)
unnamed: U$1.9, U$4.P$23 (DIGIT3)
unnamed: U$1.10, U$4.P$24 (SEG_F)
unnamed: U$1.12, U$4.P$26 (SEG_G)
unnamed: U$1.13, U$4.P$27 (SEG_A)
unnamed: U$2.2, U$5.P$16 (DIGIT2)
unnamed: U$2.3, U$5.P$17 (DIGIT5)
unnamed: U$2.4, U$5.P$18 (DIGIT8)
unnamed: U$3.1, U$6.P$15 (DIGIT1)
unnamed: U$2.6, U$5.P$20 (DIGIT4)
unnamed: U$2.7, U$5.P$21 (DIGIT7)
unnamed: U$2.8, U$5.P$22 (DIGIT6)
unnamed: U$2.9, U$5.P$23 (DIGIT3)
unnamed: U$2.10, U$5.P$24 (SEG_F)
unnamed: U$3.2, U$6.P$16 (DIGIT2)
unnamed: U$3.3, U$6.P$17 (DIGIT5)
unnamed: U$3.6, U$6.P$20 (DIGIT4)
unnamed: U$3.8, U$6.P$22 (DIGIT6)
unnamed: U$3.9, U$6.P$23 (DIGIT3)
unnamed: U$3.10, U$6.P$24 (SEG_F)
unnamed: U$2.16, U$5.P$25 (SEG_D)
unnamed: U$2.12, U$5.P$26 (SEG_G)
unnamed: U$2.13, U$5.P$27 (SEG_A)
unnamed: U$3.16, U$6.P$25 (SEG_D)
unnamed: U$3.12, U$6.P$26 (SEG_G)
unnamed: U$3.13, U$6.P$27 (SEG_A)
unnamed: U$1.14, U$4.P$1 (SEG_C)
unnamed: U$1.15, U$4.P$2 (SEG_E)
unnamed: U$1.16, U$4.P$25 (SEG_D)
unnamed: U$4.P$14 (ID3), U$5.P$14 (ID3), U$6.P$14 (ID3), U$9.P3
unnamed: U$4.P$13 (ID2), U$5.P$13 (ID2), U$6.P$13 (ID2), U$9.P2
unnamed: U$4.P$12 (ID0), U$5.P$12 (ID0), U$6.P$12 (ID0), U$9.P0
unnamed: U$4.P$11 (ID1), U$5.P$11 (ID1), U$6.P$11 (ID1), U$9.P1
unnamed: U$4.P$9 (MODE), U$5.P$9 (MODE), U$6.P$9 (MODE), U$9.P4
unnamed: U$2.14, U$5.P$1 (SEG_C)
unnamed: U$2.15, U$5.P$2 (SEG_E)
unnamed: U$9.A0, U$11.P$2
unnamed: U$3.14, U$6.P$1 (SEG_C)
unnamed: U$3.15, U$6.P$2 (SEG_E)
unnamed: U$9.A1, U$11.P$5
unnamed: U$3.11, U$6.P$3 (SEG_B)
unnamed: U$2.11, U$5.P$3 (SEG_B)
unnamed: U$9.A2, U$11.P$8
unnamed: U$6.P$8 (~WRITE), U$9.P7
unnamed: U$5.P$8 (~WRITE), U$9.P6
unnamed: U$4.P$8 (~WRITE), U$9.P5
unnamed: U$1.20, U$7.1
unnamed: U$4.P$7 (ID7(DATA_COMING)), U$4.P$10 (ID4(~SHUTDOWN)), U$4.P$19 (VDD), U$5.P$7 (ID7(DATA_COMING)), U$5.P$10 (ID4(~SHUTDOWN)), U$5.P$19 (VDD), U$6.P$7 (ID7(DATA_COMING)), U$6.P$10 (ID4(~SHUTDOWN)), U$6.P$19 (VDD), U$9.VDD, U$11.P$1, U$11.P$6, U$11.P$7, U$27.5
unnamed: U$1.19, U$7.2
unnamed: U$1.18, U$7.3
unnamed: U$1.17, U$7.4
unnamed: U$1.5, U$7.5
unnamed: U$2.20, U$7.6
unnamed: U$2.19, U$7.7
unnamed: U$2.18, U$7.8
unnamed: U$2.17, U$7.9
unnamed: U$9.SDA, U$27.1
unnamed: U$9.SCL, U$27.2
unnamed: U$3.17, U$27.10
unnamed: U$3.18, U$27.9
unnamed: U$3.5, U$27.6
unnamed: U$3.19, U$27.8
unnamed: U$3.20, U$27.7

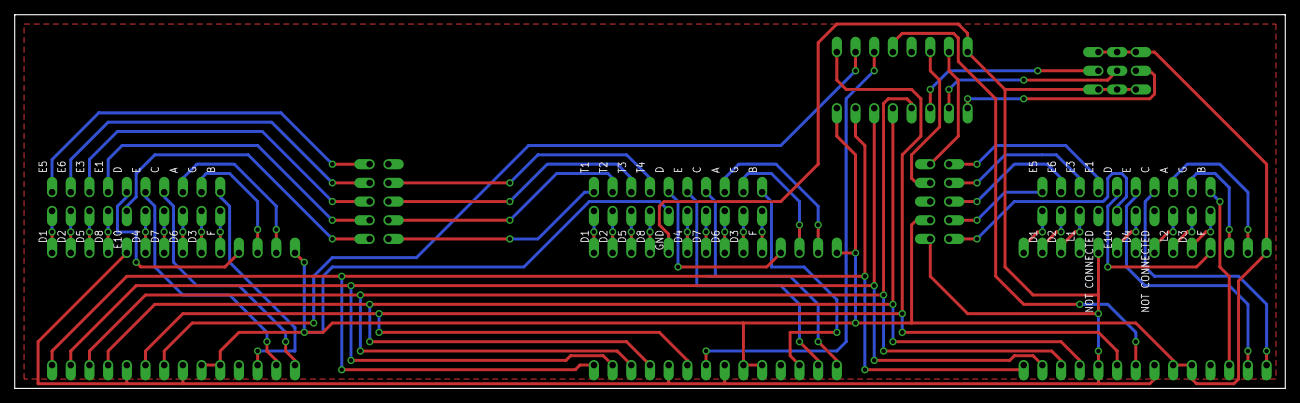
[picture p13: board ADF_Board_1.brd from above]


Board: 2 copper layers, 172.7 x 50.8 mm, 10 parts (4 on the bottom side), 72 nets.

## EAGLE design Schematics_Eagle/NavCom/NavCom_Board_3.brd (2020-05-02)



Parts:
33PF: 33pF; KONDENZATOR
CONNECTOR2: LISTA_2X5
CONNECTOR_LEFT: LISTA_2X5
U$1: MCP23016
U$2: LISTA_2X5
U$3, U$4, U$5, U$6: LS7084
U$7, U$9, U$10, U$13, U$14, U$15, U$17, U$18, U$19, U$20, U$21, U$22, U$30, U$31, U$32, U$33, U$36, U$38, U$39: REZISTOR
U$8, U$12, U$16: 470Ω; REZISTOR
U$11: ADRESA_0..2
U$23: 3.9k; REZISTOR
U$24, U$44: 103; KONDENZATOR
U$25, U$26, U$28, U$37, U$42, U$43: KONDENZATOR
U$27, U$34, U$40, U$41: 470M; REZISTOR
U$29, U$35: 4.7k; REZISTOR

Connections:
unnamed: CONNECTOR2.10, U$7.P$1, U$29.P$2, U$37.P$1
unnamed: CONNECTOR2.9, U$9.P$1, U$30.P$2
unnamed: CONNECTOR2.8, U$10.P$1, U$31.P$2, U$42.P$1
unnamed: CONNECTOR2.6, U$12.P$1, U$33.P$2, U$44.P$1
unnamed: U$5.P$4 (A), U$33.P$1
unnamed: CONNECTOR2.7, U$17.P$1, U$32.P$2, U$43.P$1
unnamed: 33PF.P$1, CONNECTOR2.4, U$1.VSS1, U$1.VSS2, U$1.VSS3, U$2.6, U$3.P$3 (VSS), U$4.P$3 (VSS), U$5.P$3 (VSS), U$6.P$3 (VSS), U$11.P$3, U$11.P$4, U$11.P$9, U$24.P$2, U$25.P$2, U$26.P$2, U$27.P$2, U$28.P$2, U$34.P$1, U$37.P$2, U$40.P$1, U$41.P$1, U$42.P$2, U$43.P$2, U$44.P$2
unnamed: CONNECTOR2.5, U$1.GP1.6, U$1.VDD, U$2.7, U$3.P$2 (VDD), U$3.P$6 (X4/X1), U$4.P$2 (VDD), U$4.P$6 (X4/X1), U$5.P$2 (VDD), U$5.P$6 (X4/X1), U$6.P$2 (VDD), U$6.P$6 (X4/X1), U$7.P$2, U$8.P$1, U$9.P$2, U$10.P$2, U$11.P$1, U$11.P$6, U$11.P$7, U$12.P$2, U$13.P$1, U$14.P$1, U$15.P$1, U$16.P$1, U$17.P$2, U$18.P$1, U$19.P$1, U$20.P$1, U$21.P$1, U$23.P$1
unnamed: CONNECTOR_LEFT.1, U$16.P$2, U$24.P$1, U$35.P$2
unnamed: CONNECTOR_LEFT.2, U$13.P$2, U$25.P$1, U$36.P$2
unnamed: U$1.GP1.4, U$22.P$1
unnamed: CONNECTOR_LEFT.4, U$15.P$2, U$26.P$1, U$38.P$2
unnamed: CONNECTOR_LEFT.5, U$18.P$2, U$28.P$1, U$39.P$2
unnamed: U$6.P$4 (A), U$39.P$1
unnamed: U$4.P$4 (A), U$32.P$1
unnamed: CONNECTOR_LEFT.9, U$1.GP0.7, U$8.P$2
unnamed: U$5.P$5 (B), U$31.P$1
unnamed: U$1.GP1.5, U$30.P$1
unnamed: U$4.P$5 (B), U$29.P$1
unnamed: U$3.P$4 (A), U$35.P$1
unnamed: CONNECTOR_LEFT.3, U$14.P$2, U$22.P$2
unnamed: U$4.P$1 (RBIAS), U$27.P$1
unnamed: U$6.P$5 (B), U$36.P$1
unnamed: U$1.GP0.2, U$4.P$7 (UP/DN)
unnamed: U$1.GP1.2, U$4.P$8 (CLK)
unnamed: U$1.A2, U$11.P$8
unnamed: U$3.P$1 (RBIAS), U$40.P$2
unnamed: U$5.P$1 (RBIAS), U$34.P$2
unnamed: CONNECTOR_LEFT.8, U$1.GP0.6, U$19.P$2
unnamed: U$1.GP0.3, U$5.P$7 (UP/DN)
unnamed: U$1.GP1.3, U$5.P$8 (CLK)
unnamed: U$1.GP1.0, U$3.P$8 (CLK)
unnamed: U$1.GP0.0, U$3.P$7 (UP/DN)
unnamed: U$1.GP1.1, U$6.P$8 (CLK)
unnamed: U$6.P$1 (RBIAS), U$41.P$2
unnamed: U$1.A1, U$11.P$5
unnamed: U$1.GP0.1, U$6.P$7 (UP/DN)
unnamed: U$1.A0, U$11.P$2
unnamed: 33PF.P$2, U$1.CLK, U$23.P$2
unnamed: CONNECTOR2.1, U$1.SDA, U$2.10
unnamed: CONNECTOR2.2, U$1.SCL, U$2.9
unnamed: U$1.~INT, U$2.4
unnamed: CONNECTOR_LEFT.7, U$1.GP0.5, U$20.P$2
unnamed: U$1.GP1.7, U$2.5
unnamed: CONNECTOR_LEFT.6, U$1.GP0.4, U$21.P$2
unnamed: U$3.P$5 (B), U$38.P$1



Board: 2 copper layers, 172.7 x 50.8 mm, 47 parts (36 on the bottom side), 46 nets.

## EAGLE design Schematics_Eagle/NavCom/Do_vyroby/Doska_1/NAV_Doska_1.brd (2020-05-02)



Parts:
D1, D2, D3, D4, D5, D6, D7, D8, D9, D10, D11, D12, D13, D14, D15, D16, D17, D18, D19, D20: SA3611EWA
E37#1, E37#2: ELMA_E37
KON4, KON5, KON6: LISTA_2X10
LED1, LED2: LED_5MM
T1, T2, T3, T4: P1-0S
U$1, U$2, U$3, U$4: REZISTOR

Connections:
D1: D1.6, KON4.1
D2: D2.6, KON4.2
D3: D3.6, KON4.9
D4: D4.6, KON4.6
D5: D5.6, KON4.3
D6: D6.6, KON4.8
D7: D7.6, KON4.7
D8: D8.6, KON4.4
D9: D9.6, KON5.1
D10: D10.6, KON5.2
D11: D11.6, KON5.9
D12: D12.6, KON5.6
D13: D13.6, KON5.3
D14: D14.6, KON5.8
D15: D15.6, KON5.7
D16: D16.6, KON5.4
D17: D17.6, KON6.1
D18: D18.6, KON6.2
D19: D19.6, KON6.9
D20: D20.6, KON6.6
DRIVER1_SEG2: D1.2, D2.2, D3.2, D4.2, D5.2, D6.2, D7.2, D8.2, KON4.10
DRIVER1_SEG3: D1.3, D2.3, D3.3, D4.3, D5.3, D6.3, D7.3, D8.3, KON4.12
DRIVER1_SEG4: D1.4, D2.4, D3.4, D4.4, D5.4, D6.4, D7.4, D8.4, KON4.15
DRIVER1_SEG5: D1.5, D2.5, D3.5, D4.5, D5.5, D6.5, D7.5, D8.5, KON4.16
DRIVER1_SEG8: D1.8, D2.8, D3.8, D4.8, D5.8, D6.8, D7.8, D8.8, KON4.14
DRIVER1_SEG9: D1.9, D2.9, D3.9, D4.9, D5.9, D6.9, D7.9, D8.9, KON4.11
DRIVER1_SEG10: D1.10, D2.10, D3.10, D4.10, D5.10, D6.10, D7.10, D8.10, KON4.13
DRIVER2_SEG2: D9.2, D10.2, D11.2, D12.2, D13.2, D14.2, D15.2, D16.2, KON5.10
DRIVER2_SEG3: D9.3, D10.3, D11.3, D12.3, D13.3, D14.3, D15.3, D16.3, KON5.12
DRIVER2_SEG4: D9.4, D10.4, D11.4, D12.4, D13.4, D14.4, D15.4, D16.4, KON5.15
DRIVER2_SEG5: D9.5, D10.5, D11.5, D12.5, D13.5, D14.5, D15.5, D16.5, KON5.16
DRIVER2_SEG8: D9.8, D10.8, D11.8, D12.8, D13.8, D14.8, D15.8, D16.8, KON5.14
DRIVER2_SEG9: D9.9, D10.9, D11.9, D12.9, D13.9, D14.9, D15.9, D16.9, KON5.11
DRIVER2_SEG10: D9.10, D10.10, D11.10, D12.10, D13.10, D14.10, D15.10, D16.10, KON5.13
DRIVER3_SEG2: D17.2, D18.2, D19.2, D20.2, KON6.10
DRIVER3_SEG3: D17.3, D18.3, D19.3, D20.3, KON6.12
DRIVER3_SEG4: D17.4, D18.4, D19.4, D20.4, KON6.15
DRIVER3_SEG5: D17.5, D18.5, D19.5, D20.5, KON6.16, LED1.P$2, LED2.P$2
DRIVER3_SEG8: D17.8, D18.8, D19.8, D20.8, KON6.14
DRIVER3_SEG9: D17.9, D18.9, D19.9, D20.9, KON6.11
DRIVER3_SEG10: D17.10, D18.10, D19.10, D20.10, KON6.13
E37#1_1: E37#1.1, KON4.17
E37#1_3: E37#1.3, KON4.18
E37#1_5: E37#1.5, KON4.20
E37#1_6: E37#1.6, KON4.19
E37#1_10: E37#1.10, KON4.5
E37#2_1: E37#2.1, KON6.17
E37#2_3: E37#2.3, KON6.18
E37#2_5: E37#2.5, KON6.20
E37#2_6: E37#2.6, KON6.19
E37#2_10: E37#2.10, KON6.5
GND: E37#1.2, E37#1.4, E37#1.9, E37#2.2, E37#2.4, E37#2.9, KON5.5, T1.4, T2.4, T3.5, T3.6, T4.5, T4.6, U$1.P$1, U$2.P$1, U$3.P$1, U$4.P$1
LED1: KON6.3, LED1.P$1
LED2: KON6.8, LED2.P$1
unnamed: D3.7, U$4.P$2
unnamed: D18.7, U$2.P$2
unnamed: D13.7, U$1.P$2
unnamed: D8.7, U$3.P$2
T1: KON5.20, T1.5, T1.6
T2: KON5.19, T2.5, T2.6
T3: KON5.18, T3.4
T4: KON5.17, T4.4


Board: 2 copper layers, 172.7 x 50.8 mm, 35 parts (0 on the bottom side), 62 nets.

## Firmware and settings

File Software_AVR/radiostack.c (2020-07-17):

/*************************************************************
* RadioStack v2.0
*************************************************************/
#include "radiostack.h"

static void rotary_encoders_init(void);
static bool is_module_connected(uint8_t address);
static void send_input_to_host(uint8_t* input, uint8_t input_id_min, uint8_t input_id_max);

bool input_changed = false;


int main(void) 
{
	/* NavComm 1 output variables. */
	uint8_t comm1_act[NAVCOMM_STRING_LEN]  = "-----";
	uint8_t comm1_stby[NAVCOMM_STRING_LEN] = "-----";
	uint8_t nav1_act[NAVCOMM_STRING_LEN]   = "-----";
	uint8_t nav1_stby[NAVCOMM_STRING_LEN]  = "-----";
	uint8_t navcomm1_led[NAVCOMM_LED_NUM]  = "++";

	/* NavComm 1 input variables. */
	uint8_t navcomm1_button[NAVCOMM_BUTTON_NUM]   = {0u, 0u, 0u, 0u};
	uint8_t navcomm1_encoder[NAVCOMM_ENCODER_NUM] = {0u, 0u, 0u, 0u};

	/* NavComm 2 output variables. */
	uint8_t comm2_act[NAVCOMM_STRING_LEN]  = "-----";
	uint8_t comm2_stby[NAVCOMM_STRING_LEN] = "-----";
	uint8_t nav2_act[NAVCOMM_STRING_LEN]   = "-----";
	uint8_t nav2_stby[NAVCOMM_STRING_LEN]  = "-----";
	uint8_t navcomm2_led[NAVCOMM_LED_NUM]  = "++";

	/* NavComm 2 input variables. */
	uint8_t navcomm2_button[NAVCOMM_BUTTON_NUM]   = {0u, 0u, 0u, 0u};
	uint8_t navcomm2_encoder[NAVCOMM_ENCODER_NUM] = {0u, 0u, 0u, 0u};

	usart_init();
	twi_set_freq();
	rotary_encoders_init();
	mcp23016_init(TWI_ADDRESS_NAV1_INPUT);
	mcp23016_init(TWI_ADDRESS_NAV2_INPUT);

	bool navcomm1_connected = is_module_connected(TWI_ADDRESS_NAV1_OUTPUT);
	bool navcomm2_connected = is_module_connected(TWI_ADDRESS_NAV2_OUTPUT);

	/* Write outputs to NavCom modules. */
	navcomm_output(comm1_act, comm1_stby, nav1_act, nav1_stby, navcomm1_led, TWI_ADDRESS_NAV1_OUTPUT);
	navcomm_output(comm2_act, comm2_stby, nav2_act, nav2_stby, navcomm2_led, TWI_ADDRESS_NAV2_OUTPUT);

	while (true)
	{
		/* Data incoming via USART ... */
		if (0x80 == (UCSRA & (1u << RXC)))
		{
			uint8_t display_select;

			/* Read the display select command byte. */
			usart_receive(&display_select, 1u);

			/* Read a string from a host and update specific display. Number of bytes to read
			   is dependent on length of a display on which the string will be shown. */
			switch (display_select)
			{
				case DISP_COMM1_ACT:
					usart_receive(comm1_act, NAVCOMM_STRING_LEN);
					break;

				case DISP_COMM1_STBY:
					usart_receive(comm1_stby, NAVCOMM_STRING_LEN);
					break;

				case DISP_NAV1_ACT:
					usart_receive(nav1_act, NAVCOMM_STRING_LEN);
					break;

				case DISP_NAV1_STBY:
					usart_receive(nav1_stby, NAVCOMM_STRING_LEN);
					break;

				case DISP_NAVCOMM1_LED:
					usart_receive(navcomm1_led, NAVCOMM_LED_NUM);
					break;


				case DISP_COMM2_ACT:
					usart_receive(comm2_act, NAVCOMM_STRING_LEN);
					break;

				case DISP_COMM2_STBY:
					usart_receive(comm2_stby, NAVCOMM_STRING_LEN);
					break;

				case DISP_NAV2_ACT:
					usart_receive(nav2_act, NAVCOMM_STRING_LEN);
					break;

				case DISP_NAV2_STBY:
					usart_receive(nav2_stby, NAVCOMM_STRING_LEN);
					break;

				case DISP_NAVCOMM2_LED:
					usart_receive(navcomm2_led, NAVCOMM_LED_NUM);
					break;


				default:
					break;
			}

			/* Write outputs to NavCom modules. */
			navcomm_output(comm1_act, comm1_stby, nav1_act, nav1_stby, navcomm1_led, TWI_ADDRESS_NAV1_OUTPUT);
			navcomm_output(comm2_act, comm2_stby, nav2_act, nav2_stby, navcomm2_led, TWI_ADDRESS_NAV2_OUTPUT);
		}

		if (true == input_changed)
		{
			/* This delay must be here because the LS7084 generates two pulses which
			   are separated to each other by approximately 17ms. Therefore if we wait
			   20ms only one pulse is latched (and everything works perfectly fine).
			   Update: If the delay is decreased to 15ms then decoding works more smoothly,
			   no jumps or stack problems. */
			_delay_ms(15u);

			if (true == navcomm1_connected)
			{
				navcomm_input(TWI_ADDRESS_NAV1_INPUT, navcomm1_encoder, navcomm1_button);
				send_input_to_host(navcomm1_button, NAVCOMM1_BUT_TEST, NAVCOMM1_BUT_NAV_SWAP);
				send_input_to_host(navcomm1_encoder, NAVCOMM1_ENC_COMM_INTGR, NAVCOMM1_ENC_NAV_FRACT);
			}

			if (true == navcomm2_connected)
			{
				navcomm_input(TWI_ADDRESS_NAV2_INPUT, navcomm2_encoder, navcomm2_button);
				send_input_to_host(navcomm2_button, NAVCOMM2_BUT_TEST, NAVCOMM2_BUT_NAV_SWAP);
				send_input_to_host(navcomm2_encoder, NAVCOMM2_ENC_COMM_INTGR, NAVCOMM2_ENC_NAV_FRACT);
			}

			mcp23016_latch_reset();
			input_changed = false;
		}
	}
}


/* This interrupt indicates that some input (button or rotary encoder in NAVCOM1, NAVCOM2, ADF,
   DME, XPDR or AP) changed its state - was pressed or turned. */
ISR (INT0_vect)
{
	input_changed = true;
}


static void rotary_encoders_init(void)
{
	/* Wait for MCP23016 to inicialize. */
	_delay_ms(200);

	/* Data Direction Register D - set as output (Latch Reset in MCP23016). */
	DDRD |=  (1 << DDD4);

	/* Pull-up enabled - set pin INT0 to HIGH. */
	PORTD |= (1 << PD2); 

	/* Status Register - Global Interrupt enabled. */
	SREG |=  (1 << SREG_I);

	/* General Interrupt Control Register - INT0 enable */
	GICR |=  (1 << INT0);

	/* MCU Control Register
	   0 0 - The low level of INT0 generates an interrupt request.
	   0 1 - Any logical change on INT0 generates an interrupt request.
	   1 0 - The falling edge of INT0 generates an interrupt request.
	   1 1 - The rising edge of INT0 generates an interrupt request. */
	MCUCR |=  (1 << ISC01);
	MCUCR &= ~(1 << ISC00);
}


/* This function pings a module to find out if it is connected
   to the mainboard. To ping it the function transmits one address
   byte via TWI bus. Then the function checks return code (TWI status).
   If return code is TW_MT_SLA_ACK (0x18, SLA+W transmitted, ACK received)
   then the module is considered to be connected.
   If return code is TW_MT_SLA_NACK (0x20, SLA+W transmitted, NACK received)
   then the module is considered to be not connected. */
static bool is_module_connected(uint8_t address)
{
	uint8_t twi_status;
	bool connected = false;

	twi_transmit_start();

	twi_status = twi_transmit_byte(address | TW_WRITE);

	twi_transmit_stop();

	if (TW_MT_SLA_ACK == twi_status)
		connected = true;
	else
		connected = false;

	return connected;
}


/* This function checks an input status array. If any input was changed 
   (turned, pressed or switched) then its code and value is sent to host. */
static void send_input_to_host(uint8_t* input, uint8_t input_id_min, uint8_t input_id_max)
{
	uint8_t buffer[2u];

	for (uint8_t i = 0u; i <= input_id_max - input_id_min; i++)
	{
		if (0u != input[i])
		{
			buffer[0u] = input_id_min + i;
			buffer[1u] = input[i];
			usart_send(buffer, 2u);
		}
	}
}

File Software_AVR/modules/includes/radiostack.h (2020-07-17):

/*************************************************************
* RadioStack v2.0/mcp23016
*************************************************************/
#ifndef __RADIOSTACK__
#define __RADIOSTACK__

#define F_CPU 4000000UL

#include <avr/io.h>
#include <avr/interrupt.h>
#include <util/delay.h>
#include <stdlib.h>
#include <stdbool.h>

#include "navcom.h"
#include "two_wire_interface.h"
#include "usart.h"
#include "mcp23016.h"

#define NAVCOMM_BUTTON_NUM   4u
#define NAVCOMM_ENCODER_NUM  4u

/* NavComm 1 input definition. */
#define NAVCOMM1_BUT_TEST        0u
#define NAVCOMM1_BUT_COMM_SWAP   1u
#define NAVCOMM1_BUT_IDENT       2u
#define NAVCOMM1_BUT_NAV_SWAP    3u
#define NAVCOMM1_ENC_COMM_INTGR  4u 
#define NAVCOMM1_ENC_COMM_FRACT  5u
#define NAVCOMM1_ENC_NAV_INTGR   6u
#define NAVCOMM1_ENC_NAV_FRACT   7u

/* NavComm 2 input definition. */
#define NAVCOMM2_BUT_TEST        8u
#define NAVCOMM2_BUT_COMM_SWAP   9u
#define NAVCOMM2_BUT_IDENT       10u
#define NAVCOMM2_BUT_NAV_SWAP    11u
#define NAVCOMM2_ENC_COMM_INTGR  12u 
#define NAVCOMM2_ENC_COMM_FRACT  13u
#define NAVCOMM2_ENC_NAV_INTGR   14u
#define NAVCOMM2_ENC_NAV_FRACT   15u

/* NavComm 1 output definition. */
#define DISP_COMM1_ACT     0u
#define DISP_COMM1_STBY    1u
#define DISP_NAV1_ACT      2u
#define DISP_NAV1_STBY     3u
#define DISP_NAVCOMM1_LED  4u

/* NavComm 2 output definition. */
#define DISP_COMM2_ACT     5u
#define DISP_COMM2_STBY    6u
#define DISP_NAV2_ACT      7u
#define DISP_NAV2_STBY     8u
#define DISP_NAVCOMM2_LED  9u

/*                             7 6 5 4 3  2  1  0 
   TWI address of MCP23016 is "0 1 0 0 A2 A1 A0 R/~W"
   TWI address of PCF8574A is "0 1 1 1 A2 A1 A0 R/~W"
   TWI address of PCF8574  is "0 1 0 0 A2 A1 A0 R/~W"
*/
#define TWI_ADDRESS_NAV1_OUTPUT  0x72  /* PCF8574A */
#define TWI_ADDRESS_NAV1_INPUT   0x42  /* MCP23016 */

#define TWI_ADDRESS_NAV2_OUTPUT  0x74  /* PCF8574A */
#define TWI_ADDRESS_NAV2_INPUT   0x44  /* MCP23016 */

#endif

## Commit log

2020-05-02 Initial commit. Files were taken from SVN repository without history. Only tags will be copied. This is tag #1.
    [ADF.dwg, Autopilot.dwg, DME.dwg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]
2020-05-02 This is tag #2 taken from former SVN repository.
    [ADF.dwg, ADF_Board_1.brd, ADF_Board_1.sch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]
2020-05-02 This is tag #3 taken from former SVN repository.
    [ADF.dwg, ADF_Board_1.brd, ADF_Board_1.sch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]
2020-05-02 This is tag #4 taken from former SVN repository.
    [ADF.dwg, ADF_Board_1.brd, ADF_Board_1.sch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]
2020-05-02 This is the latest state of the project as it was found on my local drive.
    [ADF.dwg, ADF_Board_1.brd, ADF_Board_1.sch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]
2020-05-08 Both XPDR boards finished.
    [XPDR_Board_1.brd, XPDR_Board_1.sch, XPDR_Board_2.brd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]
2020-05-10 - DME module finished. - Problem with incorrect pins (RST, INT) in XPDR module fixed.
    [DME_Board_1.brd, DME_Board_1.sch, DME_Board_2.brd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]
2020-07-16 Created very basic communication with host terminal: - Created "protocol" for receive from terminal to the device. Six bytes are transmitted, one command byte to select display + five bytes of the ou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
2020-07-17 - All inputs and outputs fully work with a host terminal interface. - New function is_module_connected() was created. Now it doesn`t matter if both modules (NavComm1 and NavComm2) are connected or no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
    [navcom.c, radiostack.c]
2020-07-17 - Added output control from host for LEDs. - Created new function send_input_to_host(). - Deleted unused common files (datatypes.h, iopin.c, iopin.h).
2020-08-05 - Added new version of rs2fsx project. - Written in MinGW GCC. - All displays and all rotary encoders in NavComm1 module are working together with FSX. - Buttons not implemented yet.
2020-08-08 - All COM port related functions moved to new modul rs2fsx_comport.c. - Added new function rs2fsx_init_display(). - Added new function rs2fsx_heartbeat(). - Encoders in navcomm2 module enabled.
2020-08-08 - Solved problem that radiostack was stuck during fast rotation of rotary encoders. - Displays are now automatically updated when simulation is restarted/reloaded. - Buttons enabled (ident and swap) 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
    [rs2fsx.h, rs2fsx_navcomm.h]
2020-08-09 - Added new function rs2fsx_refresh_display(). Now it is possible to change a radiostack value in simulator and this change is displayed also in HW radiostack. - All of the rotary encoder navcomm fun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
